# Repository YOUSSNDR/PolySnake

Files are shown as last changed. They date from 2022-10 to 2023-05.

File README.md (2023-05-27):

# PolySnake

<p align="center">
  
</p>

## Introduction

Nowadays, the world suffers from many natural disasters which cause **hundreds** or even **thousands** of victims every year. For example, according to [1] the 1976 Tangshan earthquake was an earthquake that hit the region around Tangshan which ravaged 85% of the buildings in the. The official report claimed **242,769 deaths**, but when considered the missing, the injured who later died, and the deaths in nearby Beijing and Tianjin, making it the deadliest earthquake in China and among the top disasters in China.  

Thus, in order to optimize the search for people who disappeared in this kind of disaster, it is important to design robots capable of sneaking into closed spaces and locate themselves in their environment which is the main goal of our project.  
However, not having yet the capacities nor the time to carry out a robot of this amplitude we will be satisfied to program our project so that it can locate himself by following red arrows for now .

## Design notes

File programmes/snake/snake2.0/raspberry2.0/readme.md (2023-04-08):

## Python program

we will be using the library Serial(from pyserial) 

#### Arduino serial
we will be using two arduino an Uno and a Nano
the serial.Serial allow us to connect the port to the python program

#### def read
here we read de value printed by the arduino nano

#### def write
here we send a value to the arduino Uno

#### def image processing
here we have to read an image in order to find out which path we need to take

### Main program
we use an infinite loop where we:
- read the arduino nano
- if the value is above 8 cm:
    - send nothing to UNO(keep going forward) 
- else if the value is 8 or under:
    - send value to UNO (stop the movment)
    - start the image processing protocol
    - send a new value to the UNO (chose a path)

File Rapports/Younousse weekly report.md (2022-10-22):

# <p align=center> <ins>POLYSNAKE</ins>    
# <p align=center> <ins>REPORTS</ins>

Soufiani

Younousse

<ins>2022/2023</ins>

## <p align=center> Session 1
<ins> 14/10 <ins>

I have started to schematizes some simple situation to visualize how the program will work.
Situation 1(left turn):
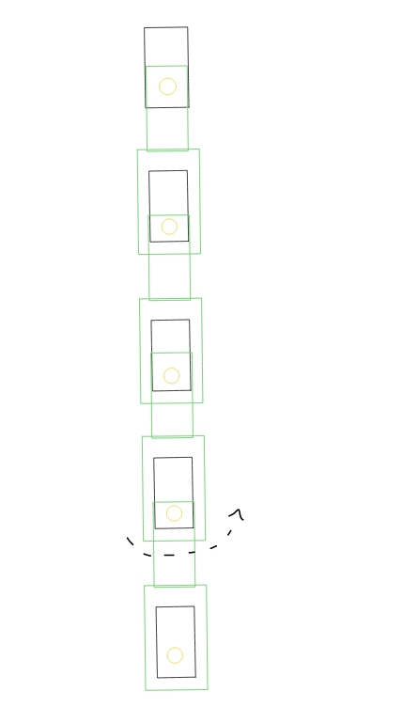
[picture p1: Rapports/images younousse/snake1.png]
how it works
  
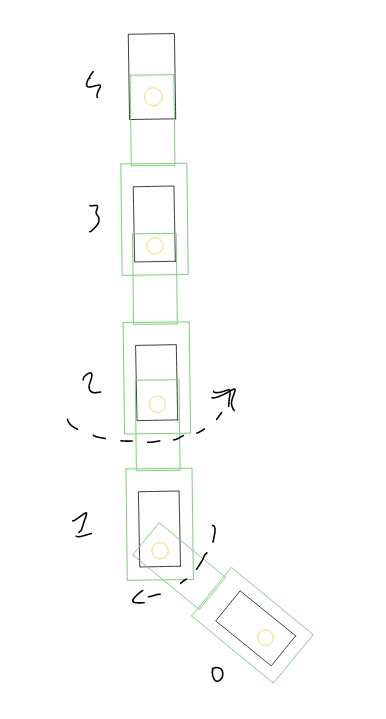
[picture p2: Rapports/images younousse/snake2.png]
how it works2

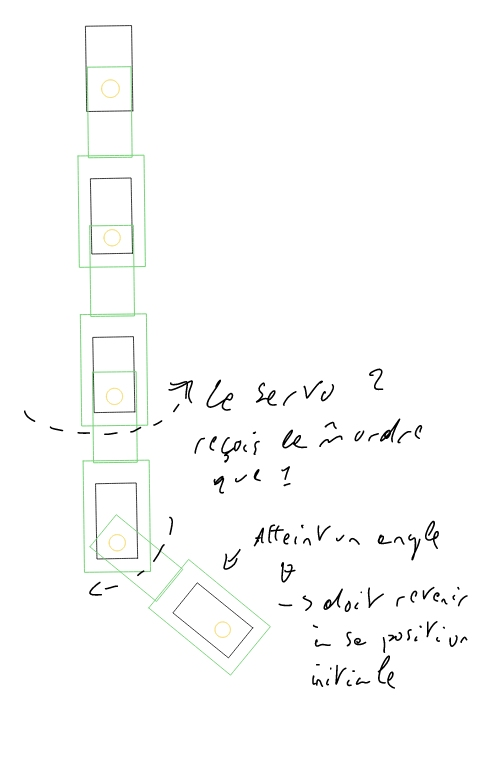
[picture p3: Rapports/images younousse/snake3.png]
how it works3

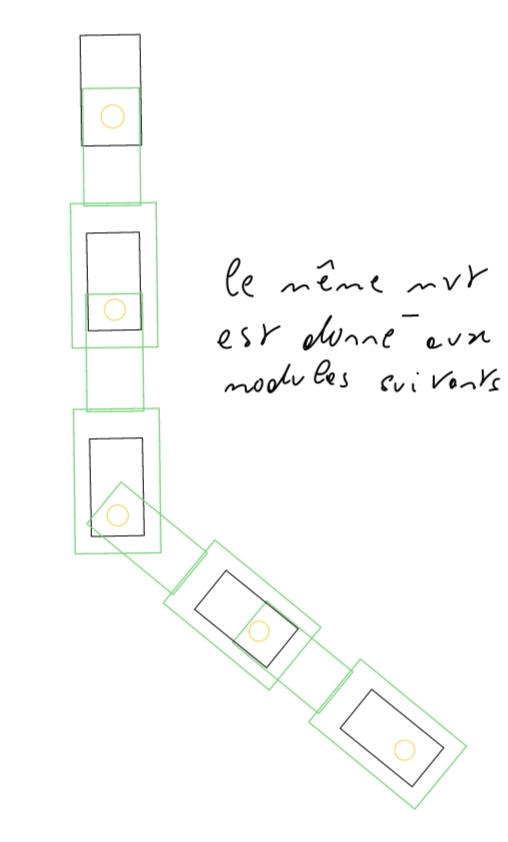
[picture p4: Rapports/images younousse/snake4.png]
how it works4


study of the servomotor and the Arduino library needed to use it.
I start by moving one servomotors then two of them.
There is the program used:
[program test1](https://github.com/YOUSSNDR/PolySnake/blob/main/programmes/servomoteurs/test1/test1.ino)
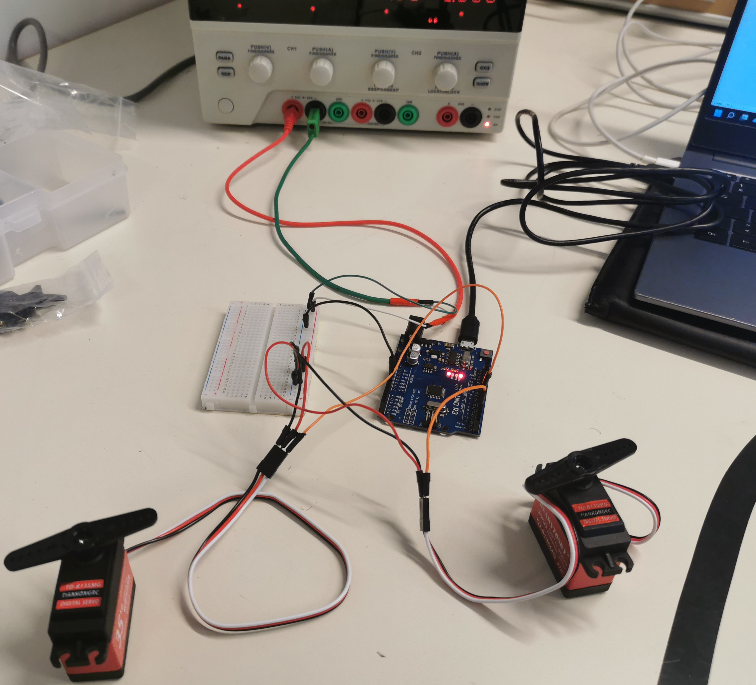
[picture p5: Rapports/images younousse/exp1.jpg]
image du test1


They are troubles with the servomotors:
- some unwanted movement
- trouble to reach the ask angle
- issues to synchronize the servomotors together
Those issues may come from the fact that those servomotors unlike the usual I use goes to 270 degrees. 
I will have to gather more data about them.

## <p align=center> Session 2
<ins>18/10</ins>

[docs about the servomotor](https://fr.aliexpress.com/item/4000538643378.html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)

i tried to find the issues by controlling the servomotors with a potentiometer and with the help of the Teacher, two source of problem were found:
- The système did not had enough courant to run properly, to fix that we will go from 400A to 850A for each servomotors.
- the servomotor had some troubles to rotate some times, we have to create some loop to avoid asking him an angle to big with not enough time.
the [program test1](https://github.com/YOUSSNDR/PolySnake/blob/main/programmes/servomoteurs/test1/test1.ino) have been improve to use the potentiometer

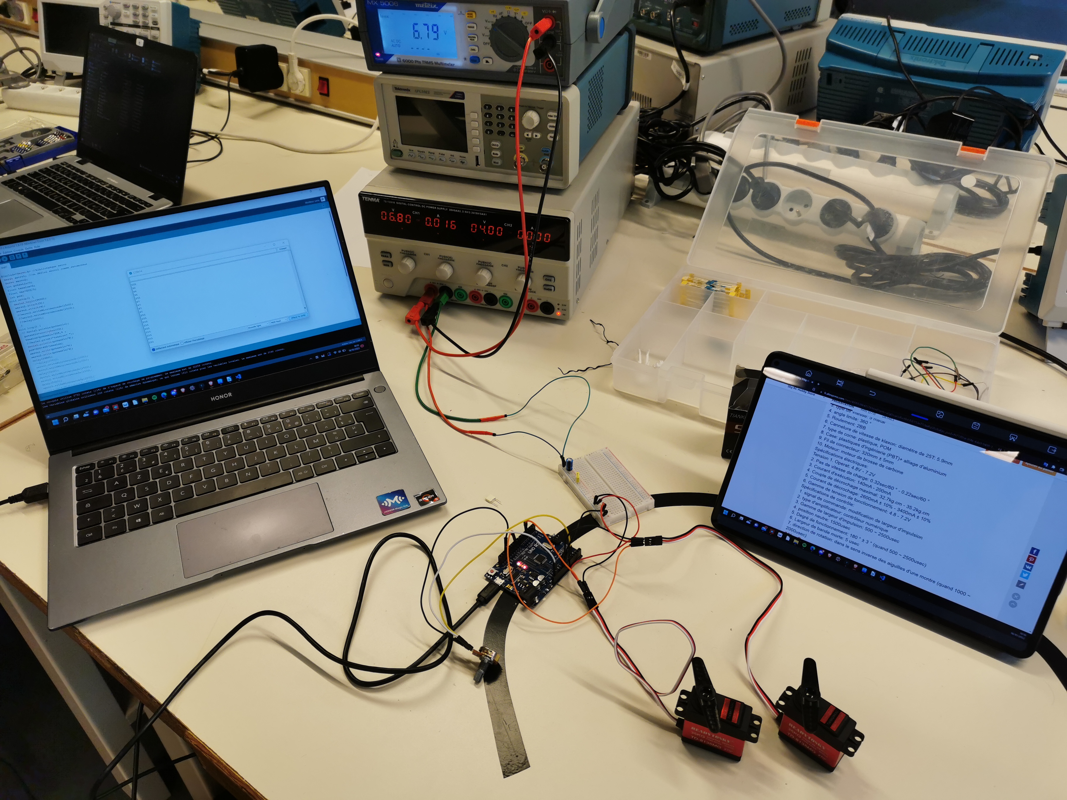
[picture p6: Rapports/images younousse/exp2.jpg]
image du test2


And so we can return to the test witheout potentiometer this time we use an other program. [program test2](https://github.com/YOUSSNDR/PolySnake/blob/main/programmes/servomoteurs/test2/test2.ino)

in it we use directly the microseconds to move the servomotors because the angle are not precise in degrees directly.

The issue look to come from the library use, it might consider 270° which is the max angle of our servomotor for 180° which is the max angle for the sevomotors often use with this library.
  
I will have to check this for the next time.

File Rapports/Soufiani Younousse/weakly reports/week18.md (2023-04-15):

## <p align=center> Session 21
<ins>11/04</ins>

Today, we work on the python program to recognise arrows thanks to a camera.
This program will allow the raspberry to choose the direction by reading an arrow.

For this program we will be using the cv2 library.
As i have never used this library before i will have to learn.
For that i searched to see if someone had ever tried making the same program before, i have found a discussion on stackoverflow on [How to detect different types of arrows in image?](https://stackoverflow.com/questions/66718462/how-to-detect-different-types-of-arrows-in-image)
and from there i have tried two programs.
They both work with the same principle, which is reading the contour to find out if it matches with the one of an arrow.

The first one i have tried was the one of stateMachine (the first one who answerd) however as i still don't master this library i could not make this one work.  
There is the program: [cameraprogram1](https://github.com/YOUSSNDR/PolySnake/blob/695c97967ed71693cd3f5189af5707c93969878c/programmes/Cam%C3%A9ra/image%20recognition%201/testimgrec1.py)  
I might come back on this one later ones i have learned enough to understand the library.

The second program comes from Prefect (another person who answered) this one i was able to make it work.  
Here is the program: [cameraprogram2](https://github.com/YOUSSNDR/PolySnake/blob/695c97967ed71693cd3f5189af5707c93969878c/programmes/Cam%C3%A9ra/image%20recognition%202/testarrowrec2.py)

For the test i use images found on the forum which are:  
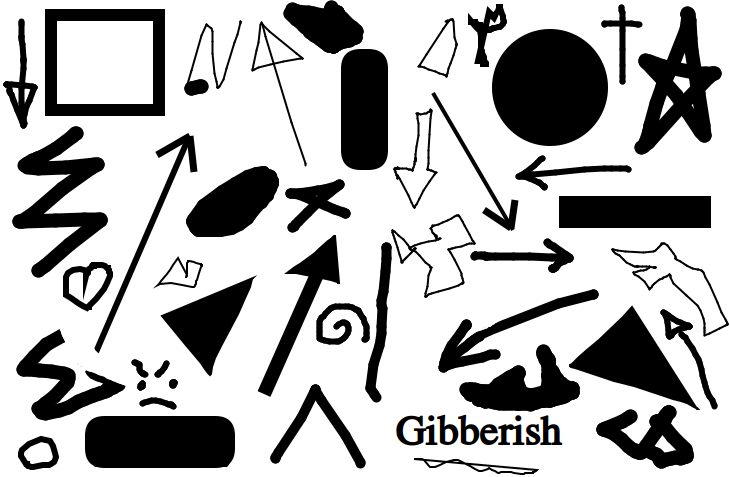
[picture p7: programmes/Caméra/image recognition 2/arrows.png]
This one   
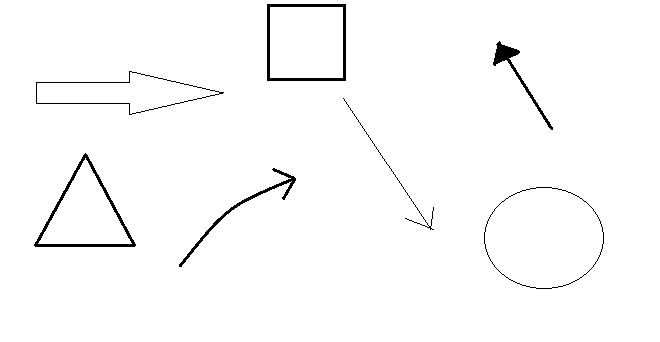
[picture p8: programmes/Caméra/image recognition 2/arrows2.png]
And this one 

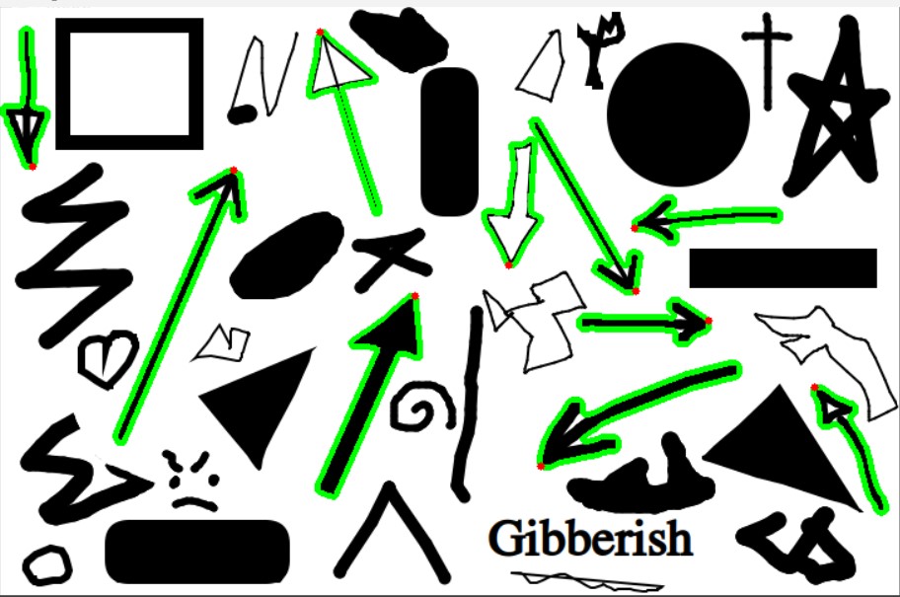
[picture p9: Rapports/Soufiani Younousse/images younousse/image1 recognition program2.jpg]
img1recpg2
The program worked perfectly with the first image   
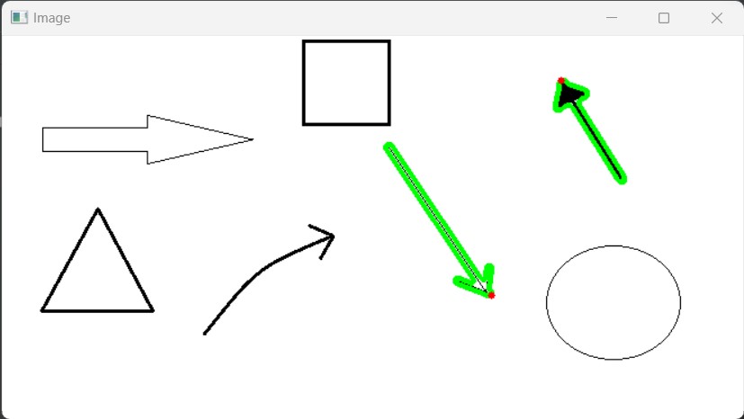
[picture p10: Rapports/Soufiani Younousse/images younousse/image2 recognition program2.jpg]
img2recpg2
But had troubles recognising all the arrows on the second image 

I have also tried getting help from chatGPT which end up with a working programm however less efficient than the other one.
The programm used is this one: [cameraprogramchatgpt]()
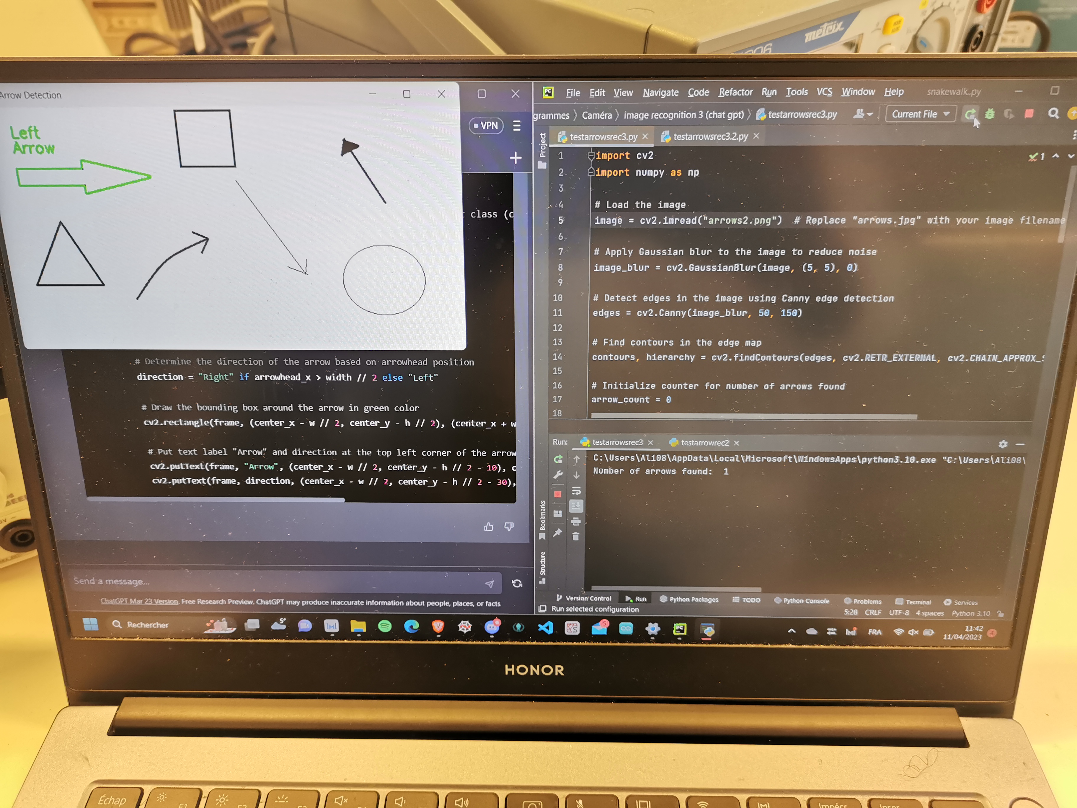
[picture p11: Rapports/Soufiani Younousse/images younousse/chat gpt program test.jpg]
img2recpgchatgpt


I will continue working on the program, Nino (a coworker) gave me a programm to try.
I will see if i can inprove it for the final use.
Guillaume (an other coworker) advise me to try to fill the arrows with easily recognisable colors for the program to detect it easier.
I will see all that.

For this session i have also took an arduino nano, which will carry the ultrasound sensor program.
I had first to weld the pin to it.

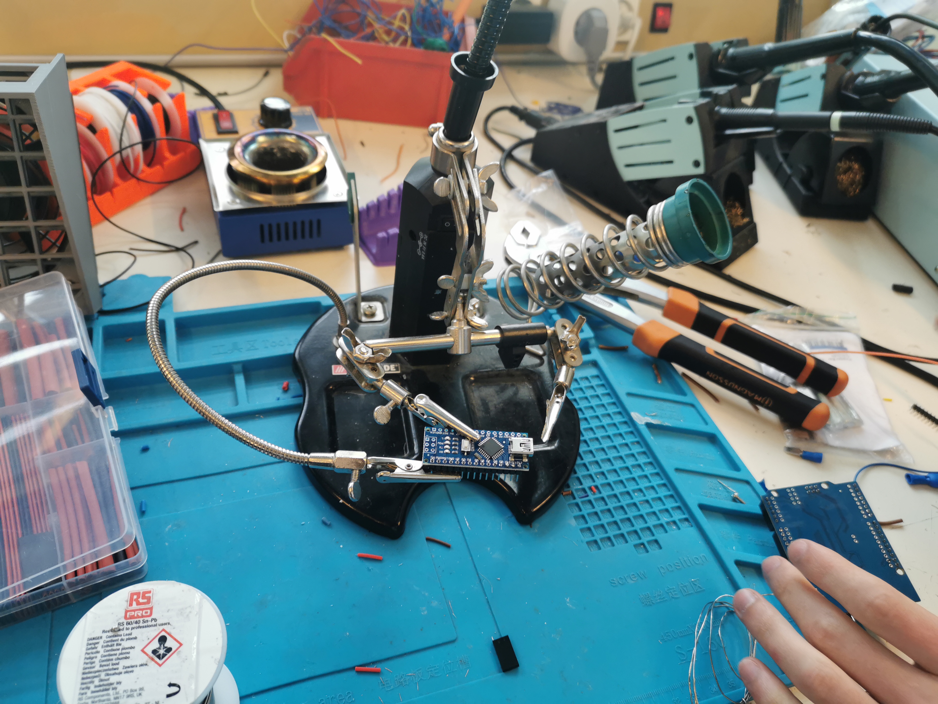
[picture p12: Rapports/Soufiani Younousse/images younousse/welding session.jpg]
welding session
Welding session: 

For the programm testing part i will have to do that at home.

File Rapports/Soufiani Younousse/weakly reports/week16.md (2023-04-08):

## <p align=center> Session 19
<ins>28/03</ins>

My goal this session was to modify the program to make it easier to use with a sensor. 
The issue we had with the program we currently use was that the main function allowing the slithering motion could not be interrupt before the end of a for loop incrementing from 0 to 360.
Which mean that the snake would have to finish his movement before changing direction (for exemple). However we want the snake to stop exactly when the order to stop is given.

Also at the end of the slithering movment the snake will stop if the function is not called again,we will also change that.

Here is the old programm (the test version): [snakewalkV5](https://github.com/YOUSSNDR/PolySnake/tree/main/programmes/servomoteurs/D%C3%A9placement/snakewalkV5.0.0)

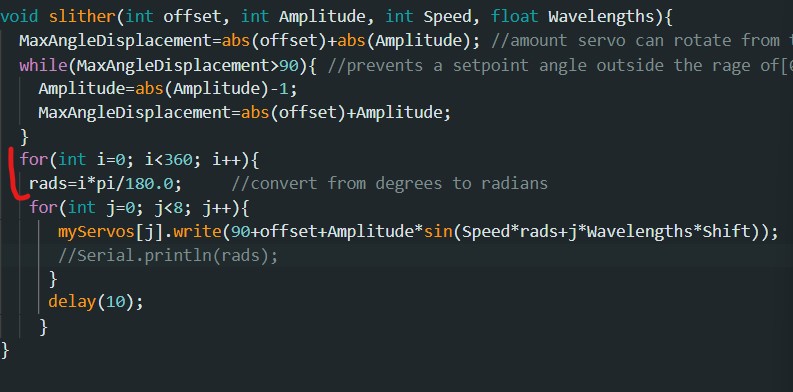
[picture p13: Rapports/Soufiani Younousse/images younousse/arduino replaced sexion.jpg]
replaced sexion
there is what we whant to change: 

I have changed the for loop by a while loop which depend on a boolean variable so that if the variable return false everything stop, else the motion never stop.

Here is the new programm: [snakewalk condition](https://github.com/YOUSSNDR/PolySnake/tree/main/programmes/servomoteurs/D%C3%A9placement/snake_walk_condition)

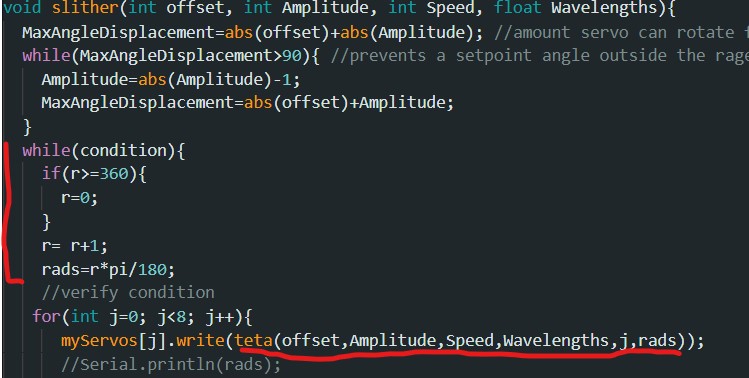
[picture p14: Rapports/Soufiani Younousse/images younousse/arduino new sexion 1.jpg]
new lines
And there are the modified lines: 

after test the new program worked just as good as the old one:
[test new program](https://drive.google.com/file/d/1erZ7xjgxGs1opVZJJl6YyXE4TiV0hOvc/view?usp=sharing)

What we will do now is add a function to modify the values in the slither function to make it turn. And for that i will use the Opencv library which allow me to send datas from python to the arduino. I have made a couple test which did not worked, the python program seems to have trouble to connect with the card, i will have to fix that.

There is the last program (not ready yet):
[New program V2](https://github.com/YOUSSNDR/PolySnake/tree/main/programmes/servomoteurs/D%C3%A9placement/snake_walk_condition2)

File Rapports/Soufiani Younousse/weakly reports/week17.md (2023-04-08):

## <p align=center> Session 20
<ins>04/04</ins>

For this session i have started by trying to find a way to keep the snake head looking at the target by assuming that in any time the sum of the angle made by all the servo motor thanks to the formula use would be constant and equal to zero, how ever i could not demonstrate it at the moment. As it is not the most important part for now i have stopped working on that.

I then switched on a main issue still left, the distance perception. To fix this issue i have choose to add an ultrasound sensor which we would use with an arduino nano. Using the arduino nano may cost more energy but thank to it we avoid Timers issues and also we will be able to read information while the snake will be moving at any time.

Now that i had the idea, i had to find a new way to make communicate the different arduino with the raspberry. I wanted to use the Opencv library but i have finally changed to the pyserial library after asking to Guillaume (a coworker).

Now that i had all the pieces of the final programm, i needed to see how they would all work together.
For that i have created markdown document explaining which program would be use where and what for. here it is -->
[programs explaination](https://github.com/YOUSSNDR/PolySnake/blob/1201f99eacff5840884c5b49c1f553cf679b7878/programmes/snake/snake.md).

All that left us with aproximatly 4 programm to create or upgrade:
- [snakewalk](https://github.com/YOUSSNDR/PolySnake/blob/1201f99eacff5840884c5b49c1f553cf679b7878/programmes/snake/snake1/arduino%20uno/snake_walk_condition/snake_walk_condition.i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) (from arduino) which need to be upgrade and adapt.
- [ultrasound sensor](https://github.com/YOUSSNDR/PolySnake/blob/1201f99eacff5840884c5b49c1f553cf679b7878/programmes/snake/snake1/arduino%20nano/distance/distance.ino) (from arduino) which also need to be upgrade and adapt.
- [communication](https://github.com/YOUSSNDR/PolySnake/blob/1201f99eacff5840884c5b49c1f553cf679b7878/programmes/snake/snake1/raspberry/python1.py) (in python) which need to be upgrade.
- and finally the camera detection part (in python) that we need to create and add in the [communication](https://github.com/YOUSSNDR/PolySnake/blob/1201f99eacff5840884c5b49c1f553cf679b7878/programmes/snake/snake1/raspberry/python1.py) program.

Also to make the communication program clearer there is a [readme](https://github.com/YOUSSNDR/PolySnake/blob/1201f99eacff5840884c5b49c1f553cf679b7878/programmes/snake/snake1/raspberry/readme.md) explaining all the function in it.

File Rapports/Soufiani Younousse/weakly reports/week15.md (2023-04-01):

## <p align=center> Session 18
<ins>21/03</ins>

In this session we have mostly tried to fix an issue on the snake.

So to start the session we wanted to try our program again to see what we could improve next, either on the snake and in the program.
But as i ve started uploading the program in the arduino we have got an error. error

after searching a bit i ve found out that some of my libraries where missing (Servo.h and cvzone.h) so i had to get them back (or at least Servo.h) to run the test.
after the installation there where no more problem with the libraries.
However in the test the snake was not totally working as it was last week.
A servomotor had troubles to turn :
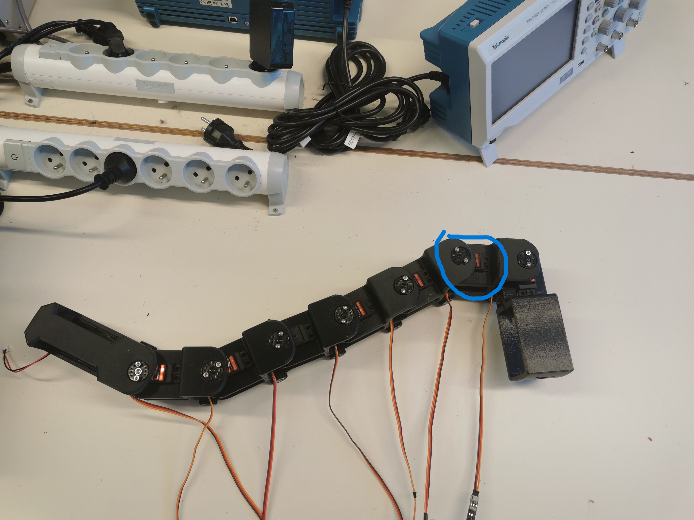
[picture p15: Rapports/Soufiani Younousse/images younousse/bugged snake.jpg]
bugged snake


The probleme looked a bit as the one we had at the start when the servomotor where struggling to reach an asked position.
To fix this issue the solution were to:
- give it enough current to run properly each servomotor.
- if that was not the solution then it meant that the servomotor did not had enough time to reach the asked position.

But here the problem did not came from those two assumption.
Audric (My coworker) Thought that maybe it was the servomotor wich did not work, So we have tried to move the servomotor separetly with a more simple program.
[servo test](https://drive.google.com/file/d/1sBgIdRgADSiTIa0Xv_KnTtk07N9oUKNa/view?usp=share_link)
And the servomotor did work, the last thing left was to verify the program.

Thank to Guillaume we have found this issue:
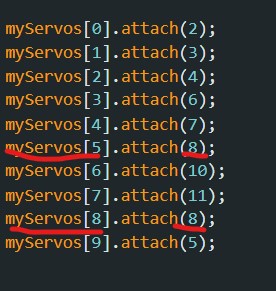
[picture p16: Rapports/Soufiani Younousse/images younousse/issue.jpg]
issue


One pin was receiving two different orders, I probably forgot to change the servo 8 pin last time i have used it and as i did not use it in the main program i thought that it would not affect the rest of the snake.
After fixing that, the snake finally worked as it should have:
[fixed snake](https://drive.google.com/file/d/1Kew2NjVZXMZn-QXQE4DfPmHUft6UFAHi/view?usp=share_link)

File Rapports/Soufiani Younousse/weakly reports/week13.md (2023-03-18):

## <p align=center> Session 16
<ins>07/03</ins>
Work on the rasberri pi zero 1W:
the .conf had trouble to work.
after a restart i have found an error in the text of the ".conf" file, after fixing it the raspberrypi finally appeard with the others devices connected to my wifi point.
normally to use the ssh conection you need to use the command "ssh pi@raspberry" if it is on factory settings.
you will next have to enter the password witch is normally "raspberry".
after that done you will be in the terminal of the raspberry card which work like a linux terminal, you can now update an install the needed package (command: "apt update","apt upgrade").
we will need python so i have installed pyhton3 (apt install python3).
We will next have to learn openCV and install it in the raspberry.

I have update the tutorial on how to connect the raspberrypi:
[tutorial](https://github.com/YOUSSNDR/PolySnake/blob/2c97e4ca37ce17a8575b1211ac05783869601126/Raspberry%20pi/Raspberry%20pi%20zero%20config/config%20Raspberry%20pi%20zero%20W.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)

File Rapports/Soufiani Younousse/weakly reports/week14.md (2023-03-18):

## <p align=center> Session 17
<ins>13/03</ins>

For this Session we made a lot of tests and verify a theorie we had.

### Cleaning Time:
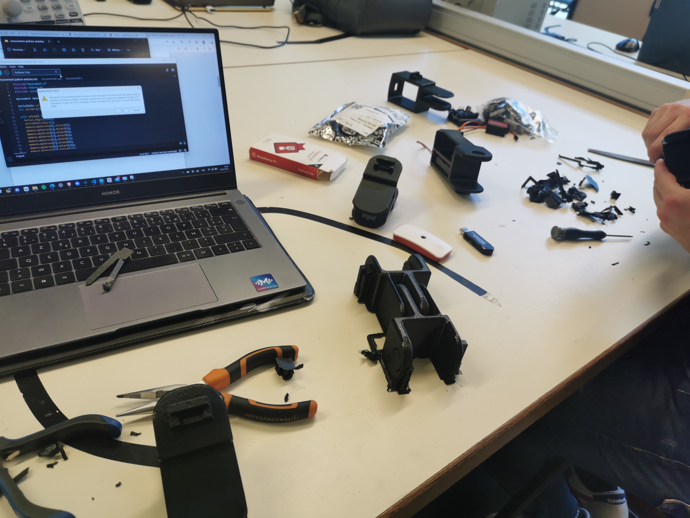
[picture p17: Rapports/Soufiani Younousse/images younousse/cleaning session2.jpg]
cleaning session2.1
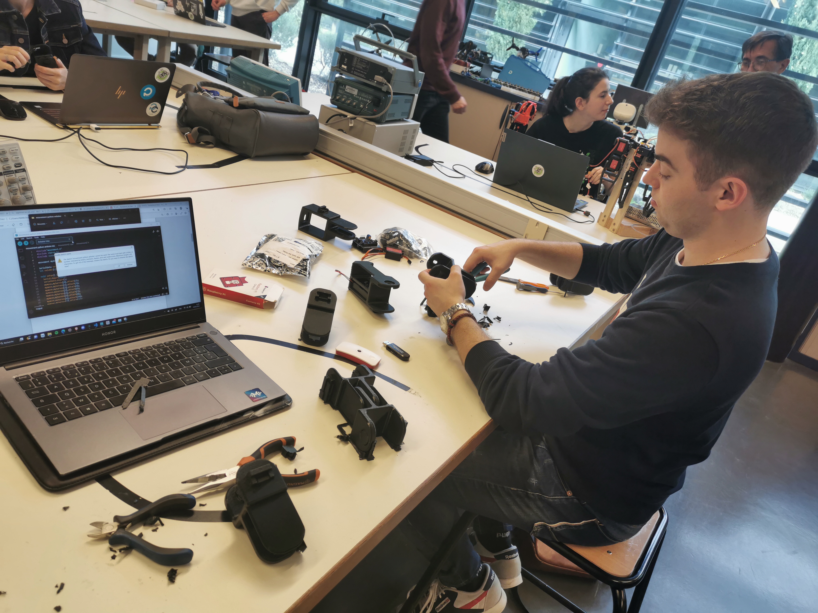
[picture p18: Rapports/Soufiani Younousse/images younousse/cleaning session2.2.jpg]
cleaning session2.2
So first we start the session by cleaning the new pieces   

Those new pieces can be mounted on wheels which will allows us to make the first tests on wheels.

### tests session:
The idea we had was that more of the work on the slithering motion was made by the friction.
And as it was pretty complicated to make a snake skin we have chosed Rubber wheels (as they will roll if the force that they receive is parallel to them and will be blocked more and more by friction as the force get perpendicular to them).
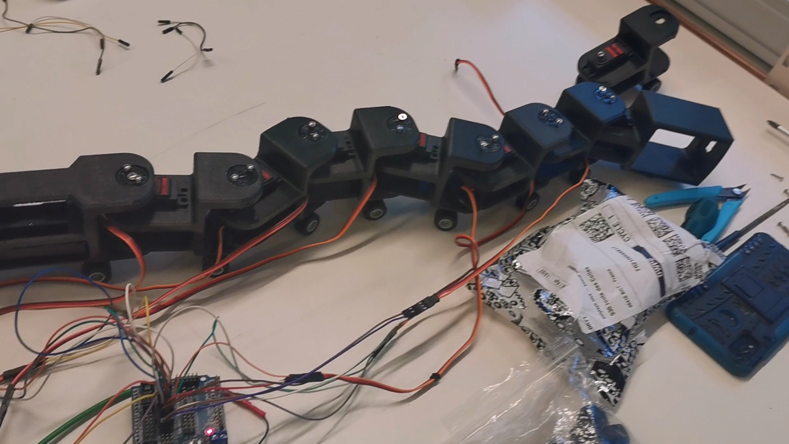
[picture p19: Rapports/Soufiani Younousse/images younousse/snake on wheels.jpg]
snake on wheels
after assembling the snake and initialising the servomotors it looked like that: 

then we used those [different program](https://github.com/YOUSSNDR/PolySnake/tree/main/programmes/Classes/mouvement) to make it move:

- the first test worked but with some troubles, as the snake make movement that are too big we have to much friction.
However we can modify parameters on the snake movement in the program. 
- After multiple test we have understood that we needed to find an equilibrium between Amplitude and Wavelength (at some point to increase the the amplitude but avoid to much friction we needed to increase wavelengths which actually decrease the amplitude).
- we saved the characteristics which where working good togethers an offset of 3(to regulate a default either on the conception or in the initialisation which was making the snake going lightly to the right) an amplitude of 43, a speed and a wavelength of 2 (those measures have not equivalent with reality for now as the different characteristics change as we modify the pieces so we need to take mesurements to find the coeficient given in reality). 

the line of code looked like this in the code: 

slither(3,43,2,2)

here are some footage of the snake slithering thanks to the wheels:
[snake on wheels2 ](https://drive.google.com/file/d/16HxC7rm6nMEpBZPa2jUxAVyJ_MZUEDOj/view?usp=share_link), [snake on wheels3](https://drive.google.com/file/d/110NtvDqg1qCNGc-kb5Mu2t1d70bv_1B8/view?usp=share_link)

### Research:
To verify my thoughts i have looked for articles one of them made some good points ([the article](https://www.pnas.org/doi/10.1073/pnas.0812533106)).
I have noted a couple sentences which where going with my thought:
- unlike most other terrestrial organisms of this size, body inertia is not central to slithering locomotion. Motion instead arises by the interaction of surface friction and internal body forces.
- these scales provide the snake a preferred direction of sliding on surfaces of sufficient roughness and compliance
- Another aspect that we have not considered is that snakes are likely able to dynamically change their frictional interactions with a surface by adjusting the attitude of their scales

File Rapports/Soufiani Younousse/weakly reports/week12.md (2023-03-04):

## <p align=center> Session 15
<ins>28/02</ins>
Work on the program: i have tryed a new way to cut the slither program with a "switch-case", but i could not test this [new program](https://github.com/YOUSSNDR/PolySnake/blob/b902d92297fb181699cc290238d12c17dca581ae/programmes/test/test%20mouvement/snakewalk-case4.ino/snakewalk-case4.ino.ino) yet.
here we only kept four cases as said in the last session:
- line (snake in line)
- slither (the snake go forward)
- slither right (the snake take a right turn)
- slither left (the snake take a left turn)
- stop (the snake stop his mouvement)

Also we will have to modify another point on the slither program so that we can get an endless loop which the "switch-case" will modify.

Verification of the component, as the Raspberry pi zero 2W is on limited stock it was much harder to found, We finally selected [this product](https://fr.aliexpress.com/item/1005003496928208.html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).

I have also worked on another way to work with the raspberry pi (if equiped with wifi) by using ssh.
It is not finished yet but i am also writing down all the details on how to connect the raspberry pi so that the tutorial could be used for the next Raspberry pi and also by someone else.
Here is the [tutorial](https://github.com/YOUSSNDR/PolySnake/blob/b902d92297fb181699cc290238d12c17dca581ae/Raspberry%20pi/Raspberry%20pi%20zero%20config/config%20Raspberry%20pi%20zero%20W.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) (not finished yet).

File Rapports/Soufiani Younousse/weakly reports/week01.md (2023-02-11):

# <p align=center> <ins>POLYSNAKE</ins>    
# <p align=center> <ins>REPORTS</ins>

Soufiani

Younousse

<ins>2022/2023</ins>

## <p align=center> Session 1
<ins> 14/10 <ins>

I have started to schematizes some simple situation to visualize how the program will work.
Situation 1(left turn):
how it works  
how it works2
how it works3
how it works4

study of the servomotor and the Arduino library needed to use it.
I start by moving one servomotors then two of them.
There is the program used:
[program test1](https://github.com/YOUSSNDR/PolySnake/blob/main/programmes/servomoteurs/test1/test1.ino)
image du test1

They are troubles with the servomotors:
- some unwanted movement
- trouble to reach the ask angle
- issues to synchronize the servomotors together
Those issues may come from the fact that those servomotors unlike the usual I use goes to 270 degrees. 
I will have to gather more data about them.

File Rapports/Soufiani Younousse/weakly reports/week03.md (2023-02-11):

## <p align=center> Session 3
<ins>28/10</ins>

### <ins>Homework</ins>

I had to verify the angle at home in order to do that i had plan to :
- first ask the servomotors for an 90° angle to see if it shows the center
- then ask him an angle of 180° to see how the library work 

However being at home i did not had acces to an efficient generator so the servomotor was strugling to get to the asked angle.

My solution was to create a loop asking him to move angle by angle while letting him enough time to reach each one of those.
to fond the needed time i have used the [docs about the servomotor](https://fr.aliexpress.com/item/4000538643378.html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) which give the rotational speed in both direction and chosed there the biggest time.
which left me with 0.32s/60° convert that giving me a little less than <span style="color:red">0.006s/1°</span>.

That left me with this code:
 [program test angles](https://github.com/YOUSSNDR/PolySnake/blob/main/programmes/servomoteurs/test_angles/test_angles2/test_angles2.ino)
 the program worked but still strugle at the initialisation.

### <ins>ClassWork</ins>

I have started by some simple test to move one servo motor but it was strugling to move even with a generator.
The reason was a missunderstood of myself the generator only limitate to some intensity and the servomotor take the intensity it need so  i had to go to 1.2A on the generator even knowing that the [docs about the servomotor](https://fr.aliexpress.com/item/4000538643378.html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) ask for 0.2A.

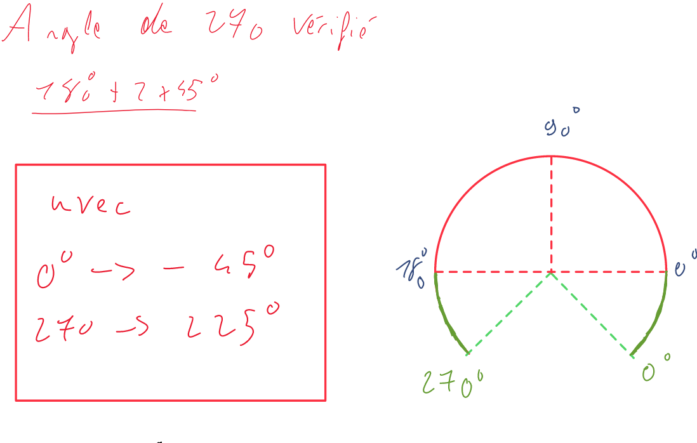
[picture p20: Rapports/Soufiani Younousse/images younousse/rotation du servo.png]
Rotation du servo
then using an upgrade of the program test2 [program test2_2](https://github.com/YOUSSNDR/PolySnake/blob/main/programmes/servomoteurs/test2/test2_2.ino) i have verified the minimum and maximum angles. an obtained this 

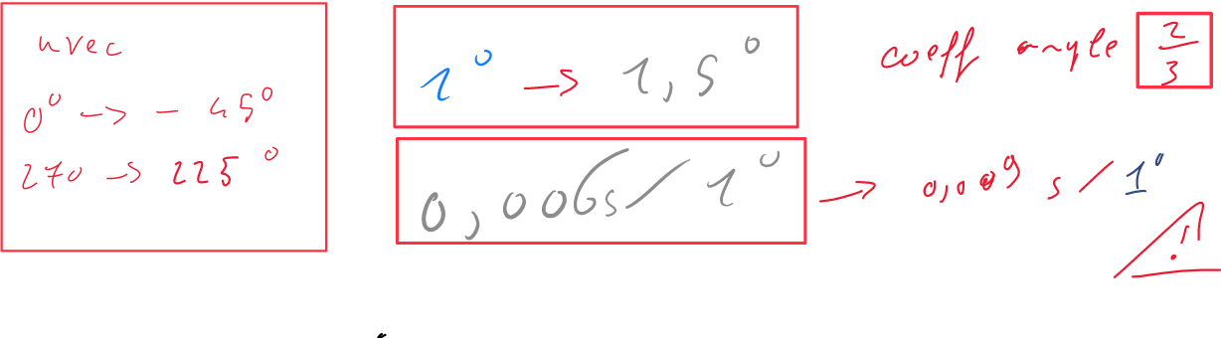
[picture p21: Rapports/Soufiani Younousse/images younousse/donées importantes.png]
donées importantes
which give us a <span style="clor:red">coefficient of 2/3</span> betwin the asked angle and the obtain angle which give us those important datas 

i have also been able to try two servomotors moving at the same time with the create program [snake walk](https://github.com/YOUSSNDR/PolySnake/blob/d8df9ac458cd2a9e06b5fb9730dac2725eff6cc4/programmes/servomoteurs/D%C3%A9placement/snake%20walk/snake%20walk.ino),
which is only a test for now which will be upgrade next to mimic the snake ondulation.

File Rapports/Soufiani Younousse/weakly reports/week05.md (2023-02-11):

## <p align=center> Session 5
<ins>26/11</ins>

We have received some servomotors with 180 degrees angle which is enough for our snake and limit the risks of braking the snake by going to far on a test.

Then there was a test  of the program [snake_walkV2](https://github.com/YOUSSNDR/PolySnake/blob/d8df9ac458cd2a9e06b5fb9730dac2725eff6cc4/programmes/servomoteurs/D%C3%A9placement/snake%20walk%20V2/snake%20walk%20V2.ino) after correcting all the little mistakes made before. 
multiple issues appeared:
    - first the program which normally work in four steps had only two of them working, this was because of the conditions. Step 1 worked because of the initialisation and then step 3 always had the conditions to work.
    - The servomotors decided not to work "again", but this time not because of lack of intensity and voltage drop. I have changed the wires but still nothing moved even with some simple test programs [test3](https://github.com/YOUSSNDR/PolySnake/blob/main/programmes/servomoteurs/test3/test3.ino) and [test4](https://github.com/YOUSSNDR/PolySnake/blob/main/programmes/servomoteurs/test4/test4.ino). with the help of a teacher it finally worked, i am still not sure of why it did not worked before. the servomotors starts working rigth after the mulitmeter have been plug, for the teacher it is a fake contacte somwere (but i have changed the wires before) after that they where some litle bug but they where working. i will reduce next time the number of wires to limit the risks of fake contact (i will need some longer wires).

After that i have tried again the [snake_walkV2](https://github.com/YOUSSNDR/PolySnake/blob/d8df9ac458cd2a9e06b5fb9730dac2725eff6cc4/programmes/servomoteurs/D%C3%A9placement/snake%20walk%20V2/snake%20walk%20V2.ino). but still nothing moved they where some other mistakes in it :
        - the program was still making simultaneously the two same steps because the end condition of the two steps where matching each others.
        - even if the steps where passed still not any movement where made.

I decided after that to make a new program as this one already had multiple default at his creation as seen on week4 (already difficult with three servomotors it would be even worse with eight ) and another program would be needed to control more servomotors. It will be finished for or during next session and will be named [snake_WalkV3](https://github.com/YOUSSNDR/PolySnake/blob/main/programmes/servomoteurs/D%C3%A9placement/snake%20walkV3/snake%20walkV3.ino).

A sheet explaining how i want to make it work is available here on [snake_walkV3_sheet](https://github.com/YOUSSNDR/PolySnake/blob/main/Rapports/Soufiani%20Younousse/images%20younousse/test%20angles%20servos.pdf).
The program will use a list containing all the angle in the order they need to be ran and each servomotors will follow the list whith a shift depending on their position.

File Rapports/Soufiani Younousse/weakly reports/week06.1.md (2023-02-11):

## <p align=center> Session 6
<ins>06/12</ins>

I have worked home on the new programm [snake_WalkV3](https://github.com/YOUSSNDR/PolySnake/blob/main/programmes/servomoteurs/D%C3%A9placement/snake%20walkV3/snake%20walkV3.ino) as planed in the last session.

the goal in this new program was to make a list of angle which would have been followed by every servomotors with a shift between them in order to mimic the snake ondulation.
the issue was that i had not found a proper way to put all the servomotors in a loop.
Therefore I needed conditions in order for the loop to work as intended.
Also we needed to control the speed of those servomotors.

I tried to make a class ([move.h](https://github.com/YOUSSNDR/PolySnake/blob/main/programmes/servomoteurs/D%C3%A9placement/snake%20walkV3/move.h) [move.cpp](https://github.com/YOUSSNDR/PolySnake/blob/main/programmes/servomoteurs/D%C3%A9placement/snake%20walkV3/move.cpp))to resolve the issues of how to follow the list but the conditions case i have putted where not recognised by the c++ language.

To help me with the program my coworker lead me to a link of someone which had already worked on a snake robot before.
[programofWillDonaldson](https://github.com/WillDonaldson/Robotic-Snake/blob/master/_1D_robotic_snake/_1D_robotic_snake.ino).
in his program i have learned some important comand as "Servo myservo[10];" which he use to define 10 servomotors.
this command can simplify a lot of work as in a loop we can change servo by using a variable.

Also the movement that i wanted to replicate is on his programe with the fonction named slitther.
I have noticed the use of a mathematical formula "myServos[j].write(90+offset+Amplitude*sin(Speed*rads+j*Wavelengths*Shift));"
which does looks alike the one of an progressive plane wave.

actually the program fit with what we wanted so we have tested it with some pieces of the snake that we already had. 
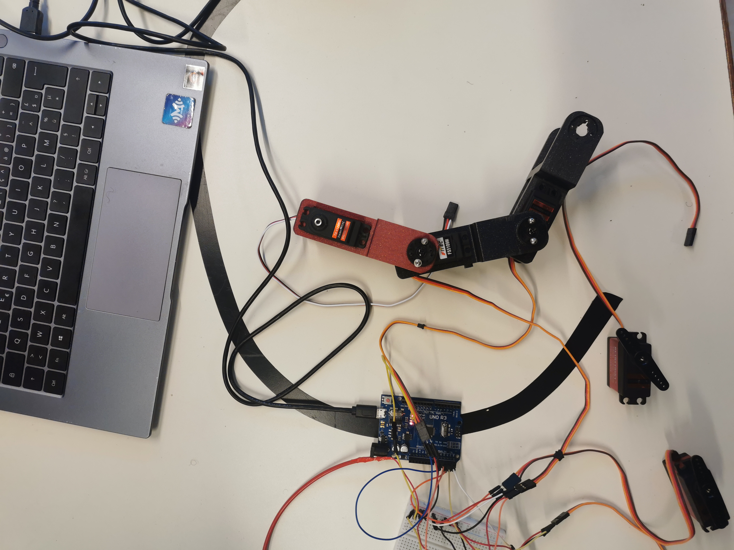
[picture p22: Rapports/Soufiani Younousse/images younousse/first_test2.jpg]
test 1

 which gave us this first result:[first_test](https://youtu.be/3seGkPpCPjw).
here the movement do not look normal because the snake was not initialise before we started the program.
So we know for the next time that while whe assemble the snake all the servomotors must be initialise with an 90° angle.

for the next session i will have to study deeper the program to make a test on a bigger snake.

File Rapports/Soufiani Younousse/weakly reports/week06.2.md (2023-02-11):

## <p align=center> Session 7
<ins>09/12</ins>

We began the session by cleaning the new 3D pieces we had as we needed them for the test.
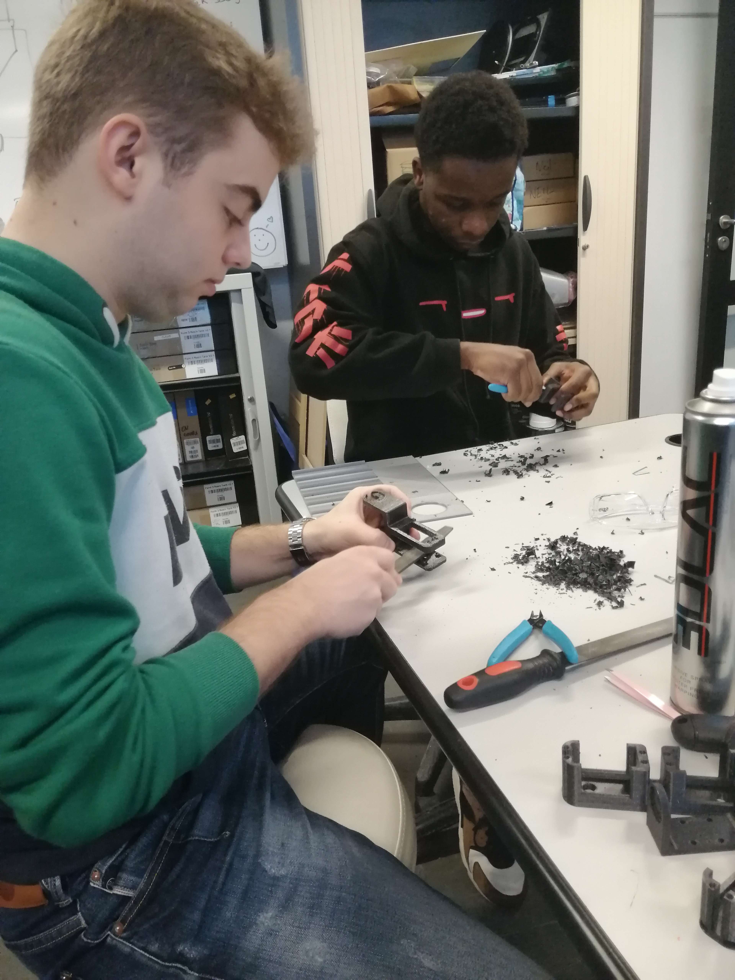
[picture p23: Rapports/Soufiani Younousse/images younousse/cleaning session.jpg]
cleaning time
 

After cleaning all the pieces we could now test the snake.
- First i prepared the programs needed while my coworker was adding the servomotors into the pieces.
- then i pluged all the servomotors so we could initialise all se servomotors at an 90° angle before attaching them (to have all the sermotors forming a straight line in the initialisation).
with [line](https://github.com/YOUSSNDR/PolySnake/blob/main/programmes/servomoteurs/D%C3%A9placement/ligne/ligne.ino)
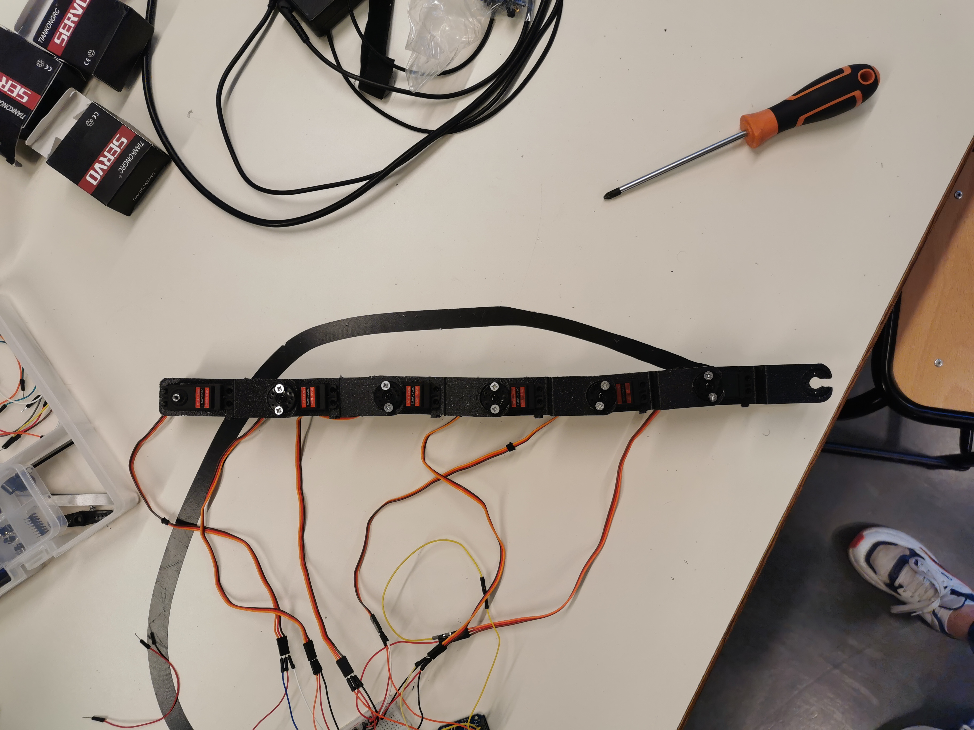
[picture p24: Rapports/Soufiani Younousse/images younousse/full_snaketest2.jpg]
snake

- And so we could start the testing with [servos_testing](https://github.com/YOUSSNDR/PolySnake/blob/main/programmes/servomoteurs/D%C3%A9placement/servos_testing/servos_testing.ino).
which are some simple order. And there is the result [Test servos](https://youtu.be/MFZg65ag1Ys).

Next test was the "snake_walk" (snake ondulation).
for it we used this program [snake walkV5](https://github.com/YOUSSNDR/PolySnake/blob/main/programmes/servomoteurs/D%C3%A9placement/snakewalkV5.0.0/snakewalkV5.0.0.ino).
And here is the result [Second test](https://youtu.be/CUl1Hz0VQxA)

the program use different variable allowing us to modify the mouvement in deffrent way:
- modify the offset allows the snake to in his moves tend to go in a direction (>0 right, <0 left).
- modify the amplitude will modify the height of the sinusoïd top.
- modify speed will increase or decrease the speed of the propagating waves.
- and modify wavelenght will make the waves more or less large.
as it use a formula which looks alike with  the one defining a progressive wave propagating on a 2D plan.

We will verify this next time.
But the main goal for the next session will be to learn how to controle an arduino device with an app.
And for another time we will try to adapt some of the program on a class.

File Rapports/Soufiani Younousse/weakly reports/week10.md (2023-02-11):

## <p align=center> Session 13
<ins>07/02</ins>

We have talked about the components we should use in order for the snake to move.
For that we have study a [video](https://www.instructables.com/Snake-Robot-1/) of a snake looking a bit like our but with multiple wheels,
what is interesting here is that apparently not anny of the wheels are motorised insted the person use the sinusoïdal mouvement which allow the snake thanks to the wheels to go forward.
We are planing on testing that as soon as we receive the wheels.

Also for all the image recognition part i will have to use a Raspberry pi Zero 1 W card which will work like a little compteur and will allow us to make an autonomous robot. In order to use the card we will need multiple component that we will have to order. After research we end up with [this list of component that we need to order](https://github.com/YOUSSNDR/PolySnake/blob/b258c2d82ef8cb8ddd8b45ca130dc0260bcdb722/Achats/Achats.md).
Among them i have put a Raspberry pi zero 2 W witch should be an improved version of the zero 1 W.
Also i have continue my work on the [Computer Vision With Arduino | 2 Hour Course | OpenCV Python](https://youtu.be/mfiRJ1qgToc).
We can now:
- command the program to stop or continue the slither motion witheout reuploading it every time
- connect the arduino board to python 
- make a communication betwin python and arduino

We have now this [arduino program](https://github.com/YOUSSNDR/PolySnake/blob/b258c2d82ef8cb8ddd8b45ca130dc0260bcdb722/programmes/servomoteurs/D%C3%A9placement/snakewalkpython-arduino/snakewalkpython-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) which can work with this [python program](https://github.com/YOUSSNDR/PolySnake/blob/b258c2d82ef8cb8ddd8b45ca130dc0260bcdb722/programmes/Arduinocv/Output/snakewalk..py).

here the value sent with arduino.sendData() in python put the snake in straightline if the value is 1 or continue the motion if the value is 0.

Now we will have to study the image recognition part and reproduce everything in the Raspberry pi.

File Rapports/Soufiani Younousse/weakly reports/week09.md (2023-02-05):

## <p align=center> Session 12
<ins>31/01</ins>

Research of a new motor for the whells, In order to get more torque we might use a continuous rotation servo motor, i have found a tutorial for how to make a continuous rotation servo motor out of a basic servo motor which could be a solution for our motor
[How_to_make_a_360_degree_Continuous_Rotation_Servo_Motor](https://youtu.be/mRO0wfSQ6jw)

We learn here that they are two major step:
- first for the mechanical part, we must flatten the last gear in order to remove the mechanical block and dril it to disconect it from the potentiometer
- then for the electronic part we must disconect the pin of the potentiometer linked to the board and on the board link the signal pin with the positive and negative pin with a resistor(same resistor for each pin)

but we should see first if they are not already made contnuous rotation servo motor.

Change of plans we will be using a material to make the modules behind the head slide on the floor while the head will guide them.
We will have to make some test to found the best motor.

Learning how to use OpenCV python for object recognition. For that i use this video [Computer Vision With Arduino | 2 Hour Course | OpenCV Python](https://youtu.be/mfiRJ1qgToc).
Which help to learn a lot of arduino basics but also some basics with OpenCV
thanks to an arduino library given in the video i will be able to make comunicate python and arduino which will allow me to modificate the mouvement witeout having to download again in the arduino uno.
I will modificate the code for this purpos and continue the video to learn about the image recognition part.

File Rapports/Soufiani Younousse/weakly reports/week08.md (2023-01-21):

## <p align=center> Session 10 and 11

### Holidays Work
for the holidays i have ask for some pieces to run some test by my own.
those pieces were:
- an arduino Sensor Shield V5.0
-  a MDD3A Motor Driver
-  a 2 axes DC 5V motor
wheels_and_MDD3A

card_and_Shield

to run all that i had a 5V power supply.
thanks to the Shiel the connections were modify giving a much clean result. I had trouble using the power supply but i have been able to try a program allowing me to use a joystick to control a servomotor.
[joystic_control](https://github.com/YOUSSNDR/PolySnake/blob/df2c1382a202e414176d68fe3e251ddcb0f33a08/programmes/servomoteurs/test%20controle%20par%20analogue/test%20controle%20par%20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)

### Algorithm course
On those course i worked on a program to detect obstacles.
My first idee was to use an ultrasound sensor to detect obstacles for therefore i took an old program i had and ad a function to move the head of the snake.

there is a photo of the ultrasound sensor working alone:
Ultrasound_sensor
there is the program and a video of the snake analysing his surounding after the slither move:
[surrounding_detection](https://drive.google.com/file/d/1-J1L_gpx6d5yrn2LekHKFwAyNEZ4aanV/view?usp=share_link)

### course session 10
<ins>13/01</ins>
We finally chose an other way for the snake to know when to make a turn, the idea is to use a rasbery pie camera to analyse the image of an arrow giving the direction the snake have to take.

So for this session i chose to work on the program to make the snake go forward or backward for that we use a DC 2 axes 5V motor, i came up with this program:
[Wheels_testprogram1](https://github.com/YOUSSNDR/PolySnake/blob/df2c1382a202e414176d68fe3e251ddcb0f33a08/programmes/Roues/premier%20test/premier%20test.ino)
there is what it looks like:
[heels_test1](https://drive.google.com/file/d/1kCXxd9m7_tPdRNpz16n7oTgrz3TyLUi4/view?usp=share_link)

but it seems that i can only make them turn at fool speed, so i tried another program to try control it:
[Wheels-testprogram2](https://github.com/YOUSSNDR/PolySnake/blob/df2c1382a202e414176d68fe3e251ddcb0f33a08/programmes/Roues/2nd%20test/2nd%20test.ino)

the program allow me to control the speed by raising the tension. We can see that the wheels start to turn at the analogic value of 50 which is around 1V. Nino advised me to use a PWM i will look for it for the next session.

As i was working on the motors my coworker which is working on the "skeleton" of the snake asked me about the max angle took by the snake in the slither move to avoid breaking the new pieces. I had to modify the program to giveme the answer:
[slither_test1](https://github.com/YOUSSNDR/PolySnake/blob/df2c1382a202e414176d68fe3e251ddcb0f33a08/programmes/test/test%20angle%20maxi/test%20angle%20maxi.ino)
So now we know that the max values taken is 120° and as our servomotors are settled on 90° we know that the max angle is 30°.

### course session 11 
<ins>16/01</ins>

#### Presentation
for the first hour and half we have prepared our presentation: I will have to show some of the works done on the snake which in my part are the program to mimic the ondulation: [snakewalk](https://github.com/YOUSSNDR/PolySnake/blob/6e268a2a5f81da5a7a2917bf6dcddee0256f1d06/programmes/servomoteurs/D%C3%A9placement/snakewalkV5.0.0/snakewalkV5.0.0.ino)
and the program to use the motors [wheels](https://github.com/YOUSSNDR/PolySnake/blob/6e268a2a5f81da5a7a2917bf6dcddee0256f1d06/programmes/Roues/premier%20test/premier%20test.ino).

the programes i have took for the presentation are first the [snakewalk_line](https://github.com/YOUSSNDR/PolySnake/blob/6e268a2a5f81da5a7a2917bf6dcddee0256f1d06/programmes/servomoteurs/D%C3%A9placement/transition%20sw-line/transition%20sw-lin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) which allows me to swhow how much can we modify the snake movement as it shows speed variation and the snake taking turn and also the [motor_first_test](https://github.com/YOUSSNDR/PolySnake/blob/df2c1382a202e414176d68fe3e251ddcb0f33a08/programmes/Roues/premier%20test/premier%20test.ino) which only shows the motors going forward full speed and backward full speed.

#### work time

After the presentation we have talked a little about the motors we would use later, we still have not chose one yet so for now i will still continue to work on the 2 axes DC 5V motor.
For my work then i have started to make the programs more clear using by classes it would make them easier to use later.
there are the program:
[movment](https://github.com/YOUSSNDR/PolySnake/tree/main/programmes/Classes/mouvement)
[motor](https://github.com/YOUSSNDR/PolySnake/tree/main/programmes/Classes/moteurs).

I will start making research for the camera and image recognition part.

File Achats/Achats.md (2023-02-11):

## Récap des Achats
#### <ins>03/02</ins>
| Objets  |
| ------ |
|[câble mini HDMI vers HDMI](https://www.amazon.fr/Rankie-C%C3%A2ble-Mini-Haute-Vitesse/dp/B01KRKO4MM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)|
|[Hub USB C(branchement C sortie USB)](https://www.amazon.fr/hub-usb-c/s?k=hub+usb+c)| 
|[adaptateur USB C(entrée) vers USB mini B(sortie)](https://www.amazon.fr/iJiZuo-Pi%C3%A8ces-Adaptateur-Connecteur-Femelle/dp/B0B7RMFMN4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)|
|[Roues Lego](https://www.amazon.com/Lego-Tire-Wheel-Long-Axles/dp/B00XZIMDFO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)|

Comme vu par mail on peut aussi remplacer le hub USB C par un hub USB mini (qui est cependant moins fréquemment utilisé).
Aussi nous pourrions aussi essayer la Raspberry pi zero 2 W qui est plus performante que la zero 1 W : [comparatif](https://raspberrytips.fr/raspberry-pi-zero-vs-zero-2/)

|[hub USB mini(branchement mini USB sorties USB)]( https://www.amazon.fr/Adaptateur-Puissance-Chargement-Raspberry-T%C3%A9l%C3%A9phone/dp/B078M3Z84Z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)|
|-----|
|[Raspberry pi zero 2 W](https://www.ldlc.com/fiche/PB00516087.html#585a4fefd91c5)|

celle-ci a besoins des mêmes éléments pour fonctionner que la zero 1 W.

Avec tout ça la Raspberry nécessitera l'utilisation de souris,clavier et écran  que nous avons normalement déjà à disposition.

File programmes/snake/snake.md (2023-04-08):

### Need to study the wheels
[how snake skin work](https://www.pnas.org/doi/10.1073/pnas.0812533106)

### Snake deplacement (what we want)
- read a distance:(we might use an arduino nano for that)
    - if to short:
        - stop the slither motion
        - look at the obstacle
        - activate the camera
        - take the order
    - else:
    - keep the slither motion 

#### For that we will use :
- an arduino nano card
- an arduino uno card 
- a raspberry zero W card

#### How will they work

- The arduino nano will take the distances continuously and advert the raspberry zero W when the limit distance is reached.

- The raspberry zero w card will be used when the limit distance is reach, it will take picture of the obstacle to know which path it should take.

- The arduino Uno card will handle the slither movment, will receive order to stop when the limit distance is reached (may ask the snake to get on line). Will receive order from the raspberry zero W to know which path it should follow.

### programm part

#### Arduino

nano:
- take the distance

Uno:
- slither motion
- cases depending on the python programme

#### Python
- receive the distance from arduino nano, if the distance is too short send a value to arduino Uno (to stop the slithering motion), then take a picture and read the information on it. 

### Etapes
#### 1) slither program for displacement arduino uno (servos)
- make a program which mimic the snake displacement

#### 2) ultra sound sensor program arduino nano 
- make a program to take the distances
- see how we will connect this arduino

#### 3) communication program raspberry pi zero W
- send message from arduino nano to raspberry pi
- treat the received datas
- send message to the arduino uno

#### 4) program traitement d'image raspberry pi zero W (Camera V2)
-

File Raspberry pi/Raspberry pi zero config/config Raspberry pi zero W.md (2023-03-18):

## Config Raspberry pi zero W

#### Intro:
    Ce document présent servira d'exemple pour une configuration de carte Raspberry pi Zero et résume ce document:
 [Raspberry_pi_Zero_W:_Installation_sans_écran_ni_clavier](https://thedatafrog.com/fr/articles/raspberry-pi-zero-headless-install/)

### Etapes:
###### - flasher une image de raspbian lite sur la carte micro SD
###### - configurer la connexion au résau wifi, et autoriser les connections à distance par ssh
###### - démarrer le pi et s'y connecter par ssh pour finaliser l'installation

####  flasher une image de raspbian lite sur la carte micro SD
ici on s'aide de ce document: [Installation rapide minimale d'un raspberry pi](https://thedatafrog.com/fr/articles/minimal-install-raspberry-pi/)

Raspbian est le système d'exploitation recommandé pour le raspberry pi. Il s'utilise un peu comme Ubuntu.

1) télécharger l'image de Raspbian lite [ici](https://www.raspberrypi.com/software/), nous utiliserons [celle-ci](liensgithub).

2) pour graver l'image on peut utiliser [Etcher](https://www.balena.io/etcher) si ce qui a était installer et une image(.img).
dns notre cas pour la gravure tout est géré dans le .exe installé avant.
imager
il suffit de:
- choisir la version voulu (pour un zero W on prendra un lite 32 bit) os selection
- séletionner l'espace de stockage (la carte mini SD)
- écrire (l'écriture et la vérification prendront environ 8 minutes).écriture

#### configurer la connexion au résau wifi, et autoriser les connections à distance par ssh

##### 1) Mise en service du SSH
les opérations suivantes peuvent être faites avec l'invite de commande windows mais ici nous utiliserons le terminal de la machine virtuel.

- on active le port USB lié à la carte SD pour la machine virtuelle.
    pour cela:
    - on ouvre la machine virtuelle et on sélectionne "configuration" MV
    - ensuite on choisit la section "USB" puis on ajoute un filtre usb port usb

- on peut maintenant rentrer les fichiers nécessaires pour le service ssh et le wifi.
    Il faut maintenant:
    - démarrer la machine virtuelle
    - aller dans "bootfs" qui sera lue comme un clé usb et y ouvrir le terminal ouverture du terminal
    - on y crée le fichier "ssh" avec la commande "touch ssh"
    - on crée ensuite le fichier "wpa_supplicant.conf" avec la commande touch wpa_supplicant.conf"
    - il faudra écrire dans ce fichier (on pourra utiliser la commande vim pour éditer le fichier)
    voici les commandes utilisés: command
    et voici le texte a rentrer dans le fichier "wpa_supplicant.conf": wpa config

On peut ensuite retirer la carte et la remettre au Raspberry pi, il faudra brancher celle-ci et attendre l'initialisation et la conexion au wifi qui devrait prendre un peu moins de 5 minutes.

##### 2) connexion SSH

une fois la connexion wifi établi, il nous faut relever l'adresse ip ou l'identifiant de la raspberry, si vous avez utilisez le partage de connexion de votre téléphone regardez dans les appareils connectés appareils connecté.

on va maintenant se connecté à la carte en SSH, pour cela on peut utiliser l'invite de commande windows(ou le terminal linux):
- on utilise la commande "ssh pi@raspberrypi" où "ssh pi@adresseip"(en remplaçant adresseip par votre adresse ip)
- on rentre ensuite le mot de passe "raspberry"

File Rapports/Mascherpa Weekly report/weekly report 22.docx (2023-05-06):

MASCHERPA Audric ROB 3 2022 / 2023

POLY-SNAKE

Weekly report n°22 from 02/05/23 :

In anticipation of the oral passage that will conclude our PolySnake project next week, we have focused on fine-tuning the details.

First, I started the week by adding capacitors to avoid voltage drops. My calculations having not borne fruit, I decided to use 1000µF capacitors which after a few tests seem to work very well on our project as shown in Figure 22.1.

Figure 22.1


After performing this step on all the servomotors, you can see the result in figure 22.2.

Figure 22.2

Once this step was completed and after restarting several welds which was the cause of bad contact and therefore poor power supply to the snake, I finally managed to power our project in 6.5V using 5 batteries varying between 1.2 and 1.5V and which allow to have a good movement of the snake using the Younousse program.


In addition, in order to be able to separate the Lego wheels, I decided to weld them together so as not to have any unpleasant surprises during the presentation of the project as in figure 22.3.1 and 22.3.2.


Figure 22.3.2

Figure 22.3.1

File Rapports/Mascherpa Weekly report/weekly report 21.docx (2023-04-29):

MASCHERPA Audric ROB 3 2022 / 2023

POLY-SNAKE

Weekly report n°21 from 17/04/23 :

Following the last session, I continued to work on the wiring of the PolySnake project. I was particularly interested in the connections between the servomotors and the pins of the Arduino board in order to be able to control them using the program we developed with my partner.

link : https://github.com/YOUSSNDR/PolySnake/tree/main/programmes

So to do this I just welded the orange cable to a male output in order to be able to connect the servomotor to the Arduino card as in figure 21.1.

Figure 21.1


After repeating this operation with all the servomotors, here is the visual result in figure 21.2.1 and 21.2.2.

Figure 21.2.1


Figure 21.2.2

After starting to test a basic program on each servomotor to check their proper functioning and the condition of all the welds, it appears that out of the 8 servomotors, 1 seems not to be powered and 2 others are connected to the same pin.

The next session will therefore be devoted to solving these problems in order to finally allow our snake to be able to operate without an external power supply.

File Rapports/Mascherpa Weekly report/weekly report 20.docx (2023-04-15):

MASCHERPA Audric ROB 3 2022 / 2023

POLY-SNAKE

Weekly report n°20 from 10/04/23 :

After the last session, I continued to work on the PolySnake connections according to Figure 20.1.


Figure 20.1

Thus, I had time to finish all the connections of the servomotors as can be seen in figure 20.2.1 and 20.2.2


Figure 20.2.1

Figure 20.2.2

During the next sessions, I will determine the capacitor adapted to our project. To do this, knowing that the calculation method gives us inconsistent results, I will test different types of capacitors until I find the one that suits and that best limits the voltage drops of the project.

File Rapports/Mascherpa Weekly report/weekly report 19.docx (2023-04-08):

MASCHERPA Audric ROB 3 2022 / 2023

POLY-SNAKE

Weekly report n°19 from 04/04/23 :


During the next sessions I will be responsible for wiring the servomotors to the power supply shown in figure 19.1

Figure 19.1

So, first of all I took care of determining the necessary capacitors in order to avoid a voltage drop in the system. I used the following equation :

E = 1/2 *C*( V1^2 - V2^2 )

With E the energy in J, C the capacitor in F and V1/V2 the voltage max and min from the voltage drop in V.


To calculate each of the elements and determine C I used the curve in figure 19.2.1 made using the assembly 19.2.2 and 19.2.3.

Figure 19.2.1

2.4V

6.4V

ΔT=250ms


Figure 19.2.2

Figure 19.2.3


So, knowing that the power supply used to operate the servomotors is 6.4V and 2A then we can determine the power in W then by knowing Δt determine the energy E:

P = V*I

P = 6,4*2=12.8W

But, E=P*Δt

E=12.8*250. 10^(-3) =3.2J

We can now determine the capacitor to use:

C= (2*E)/(V1^2 -V2^2)

C= (2*3.2)/(6,4^2 -2,4^2) =0.18F

Although the calculations were well carried out and the result must be divided by 8 due to the 8 servomotors in the Polysnake which are in parallel, 2.2mF per capacitor is an inconsistent value because it is much too large compared to the use that will to be made of it.

So, while waiting to understand where the error was made, we are going to use a 1000µF capacitor and check if the latter allows the voltage drops to be limited and change it if this is not the case.

Following this, I was able to start welding the servomotors to the power cables by adding connectors between each servomotor in order to be able to dismantle the snake once the cables are welded as

shown in figure 19.3.1 and 19.3.2.


Figure 19.3.1


Figure 19.3.2

The rest of the connections will be made during the next session.

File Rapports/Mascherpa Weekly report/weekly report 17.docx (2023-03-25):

MASCHERPA Audric ROB 3 2022 / 2023

POLY-SNAKE

Weekly report n°17 from 19/03/23 :

This session being shorter than the others, my partner and I decided to dedicate it to the search for a bug present on the movement of the polySnake. Indeed after the few tests carried out at the previous session it turned out that a servomotor did not work as we wanted.

This servomotor does not respect the instruction of the movement that we imposed on it with our program in figure 17.1.


Figure 17.1

Figure 17.2


After doing some research, it turned out that the problem did not come from the cables, nor from the Arduino card, nor from the servomotor itself, but it was a nice program that assignat two different instructions on a ping, which bugged the servo motor connected to this ping as shown in figure 17.2.

So after solving this problem we were finally able to perform the movement test on PolySnake but this time with all the body of our snake composed of 7 modules and the tail / head

Here is a link to the youtube video showing the movement of the snake using all these modules imprinted with the PETG filament :

https://www.youtube.com/watch?v=nyOi0dM7rbw

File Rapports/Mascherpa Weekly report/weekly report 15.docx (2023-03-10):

MASCHERPA Audric ROB 3 2022 / 2023

POLY-SNAKE

Weekly report n°15 from 07/03/23 :

Due to a printing problem, the 3D pieces could not be collected during this session. Thus the first tests in relation to the movements of the snake with wheels have been postponed until next week.


However, we can see in figure 15.1 part of the 3D printing of the snake's body made at the end of the week after the project session.

Figure 15.1

We can see on the left the head of the PolySnake which will contain the raspberry nano card as well as the camera and on the right the tail containing the battery and the Arduino card.

then, during the rest of this session, in order to help my partner in programming the raspberry nano card, research was carried out in order to program color and shape recognition. The ultimate goal is to allow our project to navigate in space using the red arrow as in Figure 15.2.

Figure 15.2

So here are the links to youtube videos explaining how raspberry cards and

their camera work:

https://www.youtube.com/watch?v=mNjXEybFn98

https://www.youtube.com/watch?v=-ZyFYniGUsw

https://www.youtube.com/watch?v=qfbPZbyYv8A

This video explains :

- The imports of important packages such as CV2
- Create ours trackbars
- Setting up the raspberry camera
- The PiRGBarray
- Setting up the color recognition

So the next session will be devoted to testing the movements of the snake with wheels and programming the card and the raspberry nano camera using OpenCV

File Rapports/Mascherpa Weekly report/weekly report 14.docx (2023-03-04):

MASCHERPA Audric ROB 3 2022 / 2023

POLY-SNAKE

Weekly report n°14 from 28/02/23 :

The new wheels and their supports have arrived, so the beginning of this session focused on the use of these wheels and their implementation on the 3D model.


The ultimate goal is to be able to use these wheels so that the snake can move forward only from the undulating movement and without any motorization. here is the arrangement of the wheels in figure 14.1.1

Figure 14.1.2

Figure 14.1.1

Figure 14.2


This figure is made up of 3 lego pieces 4488 (in figure 14.1.2) as well as two wheels. The objective is to be able to attach these lego pieces directly to the modules that make up the PolySnake so as not to have to use screws or nuts. We can therefore see in figure 14.2 a 3D model of the module with the area allowing the wheels to be accommodated.

Figure 14.3


We can therefore finally see a photo of the final rendering of this model with wheels in figure 14.3.

The next session will therefore be dedicated to printing all the modules as well as the head and tail of the snake and adding the wheels to them in order to check if our program allows our project to move without motorization.

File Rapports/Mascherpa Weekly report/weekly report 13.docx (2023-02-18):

MASCHERPA Audric ROB 3 2022 / 2023

POLY-SNAKE

Weekly report n°13 from 14/02/23 :

first of all, the wheels previously ordered coming from the USA, new wheels of French origin were favored in order to reduce the transport time and to have them as quickly as possible. Here are the wheels chosen in figure 13.1 very similar to the one chosen the last session.

Figure 13.1


Then, while waiting for the material to arrive, the 3D modeling of the body of the snake has been completed. The latter is inspired by all the models previously made in order to have the most optimal 3D pieces in terms of resistance, design, size, and utility.

Thus, in Figure 13.2 is a 3D model of the snake's head containing the rasebery nano card as well as the camera and space to add other items. Also in Figure 13.3 is a model of the snake's tail containing the battery (in orange) and the Arduino board (in dark blue).

Figure 13.3

Figure 13.2


It is important to emphasize that this 3D modeling aims to carry out the first tests of the advancement of the snake once the wheels have been delivered. This is why the aesthetic aspect has not yet been added.


finally, we can see in figure 13.4 the 3D modeling of the entire body of the snake.

Figure 13.4

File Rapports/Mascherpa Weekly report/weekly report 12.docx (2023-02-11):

MASCHERPA Audric ROB 3 2022 / 2023

POLY-SNAKE

Weekly report n°12 from 07/02/23 :

First of all, in view of improving our system as well as its resemblance to a snake, the engine initially planned will be removed and replaced by small wheels in figure 12.1. These last we will allow thanks to the undulating movement of the snake to move forward without using a motor.

Figure 12.1


Figure 12.2


Then, a large part of the session was centered on the wiring of the snake as well as the connection between all the servomotors, the battery, and the control board. An explanatory diagram in figure 12.2 has been produced for a better understanding.

We can see in green on the diagram the presence of a capacitor in order to avoid a drop in voltage due to the presence of a node where the cables of the servomotors will come to join the cables which will be welded to the 0 and 6.5V cables. Finally, everything will be connected to the Arduino card as well as the rasebery nano card.

To conclude, we concluded this session on the purchase of the necessary material for the brains of the snake as well as the Lego wheels and finally additional material to operate the crate rasebery nano and start programming the "brain" of the snake.

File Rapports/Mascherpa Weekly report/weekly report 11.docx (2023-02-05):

MASCHERPA Audric ROB 3 2022 / 2023

POLY-SNAKE

Weekly report n°11 from 01/02/23 :

Following the previous session and the arrival of the open day at the Polytech Sophia Nice engineering school, the focus during this session was on finishing the 3D modeling of the body of the Polysnake as well as the finalization of the program allowing him to move.


The objective was to fine-tune the details so that everything was ready for the open day. Thus, the modeling of the snake's body has been slightly modified such as the aesthetic appearance of the skull or even some slight details on the rigidity of the parts in figure 11.1.

Figure 11.1

Then, my binome and I finalized the snake program as well as its readability.

Here a link to the program : https://github.com/YOUSSNDR/PolySnake/tree/main/programmes

Finally, it was decided to use skid pads to be placed under the polysnake modules in order to reduce friction on the ground and to limit the power of the motor present in the crane of the project in figure 11.2.


Figure 11.2

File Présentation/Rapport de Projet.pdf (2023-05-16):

Rapport de Projet - PolySnake

De nos jours, le monde subit de nombreuses catastrophes naturelles qui font chaque année des centaines voire des milliers de victimes. Par exemple, selon le Discover Walks Glob , le tremblement de terre de Tangshan de 1976 était un tremblement de terre qui a frappé la région autour de Tangshan qui a ravagé 85% des bâtiments du. Le rapport officiel a fait état de 242 769 morts, mais lorsqu'on considère les disparus, les blessés qui sont décédés plus tard et les décès à Pékin et Tianjin, ce qui en fait le tremblement
de terre le plus meurtrier en Chine et l'une des principales
catastrophes en Chine.
Ainsi, afin d'optimiser la recherche des personnes disparues
dans ce genre de catastrophe, il est important de concevoir
des systèmes capables de se faufiler dans des espaces clos et


restreints afin de pouvoir venir en aide au survivant de ce genre de catastrophe naturelle.

Le poly-Snake doit donc pouvoir se faufiler dans des espaces inatteignables par l’homme pour y faire de la prise d’informations (ici prise d’image). On se limitera dans ce projet à un déplacement sur 2 axes. Pour cela nous nous sommes fixé les objectifs suivants :
- Concevoir un système embarqué intelligent
- Réaliser un programme imitant le mouvement d'un serpent
- Permettre au Poly-Snake de se diriger à l'aide de flèche rouge
- Modéliser en 3D les pièces constituant le corps du projet de A à Z
- Proposer un système entièrement démontable
- Utiliser des composants peu onéreux

A partir de ces objectifs, nous avons pu réaliser un cahier des charges listant les performances souhaitées de notre projet.

Cahier des charges :

| Fonction | Critère d’appréciation | Niveaux d’exigences
FC1 | Se déplacer | Avancer | 0,05 m/s
FC2 | Faire du repérage | Caméra | 1080p ; + 29 fps
FC3 | Détecter les obstacles | Capteur à Ultrason | ±0,3 cm
FC4 | Rentrer dans le coffre d’une voiture | Taille des modules | 40 x 30 x 20 cm

FC5 | Être esthétique | Couleur-forme | Choix libre
FC6 | Fonctionner sans branchement secteur | Batterie | +4066 mAh; +6V
FC7 | Être autonome | Mise en route -Autonomie | Bouton; [20;30 min]
FC7 | S’adapter au terrain | Résistance | Eau - Choc

Fonctionnement du PolySnake :

Une fois que notre cahier des charges était fixé, nous nous sommes intéressés au mouvement du serpent afin de comprendre comment se dernier fait pour avancer malgré son absence de membre extérieur. Il en découle que la réponse vient de la forme particulière de ces écailles. En effet les écailles du serpent sont conçues de sorte à ce qu’elles glissent sur le sol lorsqu’elles se retrouvent parallèles à la surface sur laquelle elle avance mais aussi à ce qu’elles viennent frotter le sol lorsqu’elles sont perpendiculaires à cette même surface.
C’est cette suite de frottement et de glissement qui permet au corps du serpent de se propulser sur le sol et c’est exactement le même principe que nous allons venir utiliser à l’aide de petites roues lego.


Effectivement, nous somme venu placer des roues passives en dessous de chaque module qui composent le corps du PolySnake pour remplacer ces écailles. Il en résulte que le serpent peut être propulsé vers l’avant simplement en envoyant une onde sinusoïdale le long du corps comme on peut l’observer sur le schéma ci-contre.


Par ailleurs, les modules observés précédemment sont des pièces entièrement réalisées en impression 3D qui permettent aux servomoteurs de se connecter les uns avec les autres. Cela permet à notre projet de pouvoir se mouvoir en ondulant sur le sol comme le ferait un vrai serpent uniquement en venant manipuler les mouvements des servomoteurs entre eux. On peut voir ci dessous une capture d’écran de la modélisation 3D du PolySnake avec la tête qui va venir accueillir l'émetteur à ultrason ainsi que la carte Raspberry pi zero W et la caméra Raspberry nano et la queue qui elle va venir accueillir la carte arduino et l’alimentation du projet.


Par la suite nous nous sommes intéressés au montage électrique du système complet. Ici le fonctionnement est simple, notre objectif était de venir alimenter en 6.4V les servomoteurs et la carte arduino qui composent notre serpent à l’aide de cinq piles en série variant entre 1.2V et 1.5V. De plus, le choix de l’alimentation n’a pas été pris au hasard. En effet c’est en se basant sur la datasheet des servomoteurs que nous avons pu déterminer la tension idéale pour alimenter correctement les servomoteurs sans venir les surcharger.

Schéma électrique du projet :


Algorithme de fonctionnement global du projet :

L’avance et le changement de direction du serpent sont possibles grâce au programme dans la carte arduino dont la fonction slither prend en entrée un décalage, une amplitude, une vitesse et une longueur d'onde, ce qui permet de faire osciller le serpent dans la direction désirée.
Le programme détient aussi une fonction pour arrêter le serpent si besoin.

La détection d'obstacle, la reconnaissance d’image et la prise de décision se font dans le même programme dans la raspberry pi zero W.

La distance entre le serpent et l’obstacle est constamment relevée, lorsque celle-ci est inférieur à 8 cm le serpent reçoit l’ordre de s'arrêter et la reconnaissance d’image commence.

La fonction de reconnaissance d’image cherche à savoir si la caméra détecte une flèche rouge, si oui alors elle relève la direction de celle-ci et l’envoi à la carte arduino pour que le serpent puisse prendre la nouvelle direction. Sinon le serpent est stoppé.


Le grand nombre de paramètres dans la fonction slither pourrait permettre plus de possibilité de mouvement (ex réduction des oscillation pour accéder à des espaces plus ou moins fin) mais pour le temps qui nous à été donné nous avons préféré nous concentrer sur faire avancer le serpent et lui permettre de changer de direction.


Estimation du prix du PolySnake :

Coût du projet:(9932,96€)
- matériel : (432,96€)
- ServoMoteur (TD-8135MG 180°) x8 (38,99€/pièces)
- carte Arduino Uno (12,98€)
- Carte Raspberry pi zero W (18,60€)
- Capteur à ultrason (HC-SR04) (5,99€)
- Caméra raspberry pi module V2.0 (25,80€)
- Roues (Lego) (32,90€)
- Condensateur (1000uF) x7 (0,78€/pièces)
- boitier à pile (9,99€)
- piles (x3 1,2V , x2 1,5V) (9,32€)
- Ingénieur (38K pour 1600h) en partant sur 200h/pers soit 4750€/pers

Les imprévus :
Pour ce qui à était modifié par rapport à la Bibliographie on peut trouver un changement au niveau des roues qui auraient dû être motorisées avec l’utilisation de moteur CC, le serpent final se déplace grâce au mouvement d’ondulation provoqué par les différents servomoteurs et aux frottement entre les roues et le sol. Cela nous à permis une réduction de la masse et taille du serpent, une réduction du coût total et aussi une réduction de la consommation.
On a aussi eu à ajouter des condensateurs ce qui n’était pas prévu.

Les problèmes :
L’un de nos plus grand problème était l’alimentation, Nous avions prévu à la base l’utilisation de batteries pour alimenter le projet cependant nous n’avons pas pu les commander, celles-ci ont été remplacées par des piles.
Un autre problème à régler lors du montage du serpent était celui des chutes de tension, pour régler ce problème nous avons placé des condensateurs tout au long du serpent.
Enfin pour ce qui est du capteur de distance, nous avons dû remplacer la carte arduino nano qui le contrôlait par une connexion direct à la raspberry pi zero W à cause de problèmes au niveau de la carte arduino nano, faire ce remplacement nous a aussi permis de réduire le nombre de composants.

Conclusion :

Pour conclure, ce projet à été pour nous l’occasion de travailler sur des thèmes placés au centre de l'ingénierie moderne telle que la modélisation, la conception, la programmation, etc… Il en découle que notre projet, bien que partiellement abouti, arrive à fonctionner sans aide extérieure.

En effet le PolySnake à l’aide de son alimentation 6.4V, de sa caméra raspberry pi, de son émetteur à ultrason et enfin de son programme, arriverai parfaitement à fonctionner sans aucune aide même si le programme centrale reliant la carte arduino à la carte raspberry pi n’est pas encore opérationnel.
C’est un aspect que nous souhaiterions travailler dans la suite de nos étude ainsi que le perfectionnement de la batterie et le jeu entre les servomoteurs afin de rendre notre projet 100% autonome et surtout tout terrain ce qui est actuellement l’un des plus gros problèmes du PolySnake, son manque de dynamisme sur les surfaces autres que parfaitement plane.

Bibliographie :

Bioinspired Robotic Snake:
Bioinspired Robotic Snake : 16 Steps (with Pictures) - Instructables (https://www.instructables.com/Bioinspired-Robotic-Snake/)

Snake locomotion :
Snake locomotion (louisiana.edu) (https://userweb.ucs.louisiana.edu/~brm2286/locomotn.htm)
Les serpents, ces animaux fascinants (free.fr) (http://squamata.free.fr/locomotion.htm)

The mechanics of slithering locomotion : https://www.pnas.org/doi/10.1073/pnas.0812533106

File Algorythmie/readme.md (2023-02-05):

## Algorithmie

Pour notre projet nous avons pour l'instant deux principaux programmes utiles à notre Robots:
- l'un nous permet d'imiter les ondulations des serpents "mouvement2"
- l'autre nous permet d'utiliser le moteur "moteurs2"

### moteur2
Ce programme est assez simple il nous permettra de faire avancer ou reculer le robot, pour cela on done la direction (marche avant/arrière) et une vitesse voulue sous forme d'une valeur analogique.
voici un test: [wheels_test](https://drive.google.com/file/d/1kCXxd9m7_tPdRNpz16n7oTgrz3TyLUi4/view?usp=share_link)

### mouvement2
Ce programme est un peu plus complexe, il agit sur les différents servos moteur et leur donne des angles à atteindre, ces angles sont déterminé a partir d'une fonction sinusoïdale ce qui nous permet de voir une ondulation. aussi cette fonction sinuisoïdale nous permet de controler différent éléments:
- l'amplitude du mouvement 
- la vitesse de propagation de l'onde
- la longueur d'onde.
tout ça pour donner un mouvement plus ou moins réaliste au robot.

voici un test ou on a une modification de l'amplitude, une modification de la vitesse et l'utilisation d'un décallage pour changer de direction:
[test_ondulation1](https://drive.google.com/file/d/18OSwVxILO8t3YWNuw0CFthk3nBTT0Grp/view?usp=share_link)
[test2_ondulation](https://drive.google.com/file/d/18mUrjYc68gUuUbowsBK2COEysheR3PN-/view?usp=share_link)

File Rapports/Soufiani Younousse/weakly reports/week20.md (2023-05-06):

## <p align=center> Session 23
<ins>02/05</ins>

### Arrow deterction program
I have took the work from where i left last week.
Now i have three version of the arrow detection program. 
We will sart with the [second program](https://github.com/YOUSSNDR/PolySnake/blob/dbf0446f182a6393fc1b76dd6d8bf0762ccefc0e/programmes/Cam%C3%A9ra/image%20recognition%205%20(youss)/testarrowrec5.2.py) which can now get the position of the tip of the arrow and get the center of the rectangle which can contain the arrow in order to get the direction of the arrow.
image pg2

For the [third program](https://github.com/YOUSSNDR/PolySnake/blob/2009bf68ff010cee0d42282d08546313a76a4bc5/programmes/Cam%C3%A9ra/image%20recognition%205%20(youss)/testarrowrec5.3.py) program i have changed the way the program recognise color to be more efficient the program now check if the color hue value of the pixel at the center of the contour is in a range of 0 tO 5 OR above 170 to know if it is red. this methode is more efficient as even if the brightness change the HVR mode color can help recognise the color.

for the [fourth program](https://github.com/YOUSSNDR/PolySnake/blob/2009bf68ff010cee0d42282d08546313a76a4bc5/programmes/Cam%C3%A9ra/image%20recognition%205%20(youss)/testarrowrec5.4.py) it mostly a rearrangment of the third programm.
here we choose to first check the contour to see if it match the one of an arrow and then check the color to see if it is red.
img prgm4

i have stock all the program needed for the snake on a file [snake 2](https://github.com/YOUSSNDR/PolySnake/tree/main/programmes/snake/snake2.0)

We had later trouble using the arduino nano (it would not upload any program). It may be a problem from arduino.
I will have to create a python program for the ultrasound sensor. We will be using the raspberry to control it.

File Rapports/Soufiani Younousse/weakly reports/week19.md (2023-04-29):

## <p align=center> Session 22
<ins>25/04</ins>

The work done this session can be split in two part:

### Testing part
We have strated the session by trying the [slithering program](https://github.com/YOUSSNDR/PolySnake/blob/dbf0446f182a6393fc1b76dd6d8bf0762ccefc0e/programmes/servomoteurs/D%C3%A9placement/snakewalkV5.0.0/snakewalkV5.0.0.ino) with the snake and his new connections done by Audric (my coworker).
It did not worked quite well, so we decided to use a [test program](https://github.com/YOUSSNDR/PolySnake/blob/ad8bc102a174c1b50114d60de3b588967cde8104/programmes/test/FKGXWP0K16PF6PV/FKGXWP0K16PF6PV.ino) on each servomotor one by one to see where does the problem come from.
We found out that two servomotors where sharing there connectics therefore they where both receiving two different orders at the same time.

### Arrow detection program
Before the holidays Nino gave me a program to test ([Nino's program](https://github.com/YOUSSNDR/PolySnake/blob/dbf0446f182a6393fc1b76dd6d8bf0762ccefc0e/programmes/Cam%C3%A9ra/image%20recognition%204%20(Nino)/testarrowrec4.py)). 
The program did worked but not exactly as i wanted,
as it detect not only the arrows but also all other contour.
imgpgNino

So i have started making my own program using pieces of all the four programs i have.
for now [my program](https://github.com/YOUSSNDR/PolySnake/blob/dbf0446f182a6393fc1b76dd6d8bf0762ccefc0e/programmes/Cam%C3%A9ra/image%20recognition%205%20(youss)/testarrowrec5.py) use the preprocess of the [second program](https://github.com/YOUSSNDR/PolySnake/blob/dbf0446f182a6393fc1b76dd6d8bf0762ccefc0e/programmes/Cam%C3%A9ra/image%20recognition%202/testarrowrec2.py) which make it easier to find the contours.

we next go through all the contours and take the medium color inside it thanks to the 'cv2.mean' command.

for now it only detect contour and give the medium color inside it.
there is what it looks like: imgmyprgm

We will next have to omprove the program to detect only arrow shapes in the image and among them only the one with a red color.

Ps: i have already improve the programm here you can find [my second program](https://github.com/YOUSSNDR/PolySnake/blob/dbf0446f182a6393fc1b76dd6d8bf0762ccefc0e/programmes/Cam%C3%A9ra/image%20recognition%205%20(youss)/testarrowrec5.2.py) which i will continue to improve till next report where i will also explain the new features.
here are images of the second program: img my second program

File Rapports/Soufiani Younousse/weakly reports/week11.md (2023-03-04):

## <p align=center> Session 14
<ins>14/02</ins>

- Work on the program:
    The goal was to modify the snake movement depending on the value send by python
    for that i've: 
    - listed the movement i wanted 
    - made a logical table out of them
    and so i was left with that : table_logique1 table_logique2
    (Maybe a little bit to much for the task) I have now all the movement i want to use and a number link to them.
    they are 9 cases:
        - line (snake in line)
        - slither (the snake go forward)
        - slither right (the snake take a right turn)
        - slither left (the snake take a left turn)
        - stop line (the snake get in line and wait)
        - stop left (the snake get in position to turn left then stop) 
        - stop right (the snake get in position to turn right then stop)
        - stop (the snake stop his mouvement)
            
        mouvement that we will later reduce to four:
        - line (snake in line)
        - slither (the snake go forward)
        - slither right (the snake take a right turn)
        - slither left (the snake take a left turn)
        - stop (the snake stop his mouvement)
    
    So i've tried this in a test program
    where all the case choice was made in the void loop but i have seen some issue with the slither loop in it, so i tried a new program [snakewalk-case2](https://github.com/YOUSSNDR/PolySnake/blob/15777205acda2ff8ac74c616b032026ad5cf631f/programmes/test/test%20mouvement/snakewalk-case2/snakewalk-case2.ino)
    here the case are directly in the slither loop but still they will be trouble in the program.
    I have to modify the program to be able to cut the slither fonction anywhere this would allow the stop case to work.
    i will try that on the next program and also keep the four cases to simplify it.

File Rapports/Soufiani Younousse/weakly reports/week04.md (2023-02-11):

## <p align=center> Session 4
<ins>15/11</ins>

gathering information about snake locomotion to come with a program which would mimic the snake ondulation.

we see in[Snake_Robot_Locomotion](https://www.youtube.com/watch?v=pv_MknD6jks&t=18s&pp=ugMICgJmchABGAE%3D) that their are more focused on how to pass large obstacle which for us will more likely be study after achieving making the snake serpentine while going forward.

in [how_Snakes_Move!](https://www.youtube.com/watch?v=7-AKPFiIEEw&pp=ugMICgJmchABGAE%3D ) we learn that:

- there are 4 differents locomotion for snakes 
    - srpentine locomotion
    - concertina locomotion
    - sidewinding locomotion
    - Rectilinear locomotion

those different methode are use for different envoronment.

Serpentine (lateral ondulation) is the one which we will study first as if we stick to the idea of making the robot on wheels it would at list looks like a snake.
so snake use this movement to push themselves off of objects and then push down where their body bends to move forward

the program create [snake_walkV2](https://github.com/YOUSSNDR/PolySnake/blob/d8df9ac458cd2a9e06b5fb9730dac2725eff6cc4/programmes/servomoteurs/D%C3%A9placement/snake%20walk%20V2/snake%20walk%20V2.ino) for now use only 3 servomotors which is less than the half of what we will use at the end. no test have been conduct for now with this programm as it has been finished at home.

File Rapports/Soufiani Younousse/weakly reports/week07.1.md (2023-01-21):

## <p align=center> Session 8
<ins>14/12</ins>

To start this new session we add one more module to the snake 
and fix some screw issues on the snake (some screw were to long and so were rubbing the snake).
seven_module_snake
Change of plan from what we wanted to do last week.
as with the control of his ondulation the snake can turn right and left we might use that to make it turn on wheels.
but for that we need to work the transition.
Two types of transition are to work on:
    - to make the snake form a line 
    - to turn

To line up:
    the snake will have to lose some amplitude if the path he is following is getting finer. in order to do that we use the slither function and drop the amplitude.
    But as the amplitude drops the movment looks slower so we also need to control the speed. After several test it seems that increasing the spead of 1°/s for every drop of 5 cm in amplitude give it a much better look.

To turn:
    We will need the snake to turn, for that we also use the slither function. when ask to turn the snake make the turn but to fast (it could break somthing). so we use a while loop and a delay fuction toslow down the turn.

there is a test where the turn is to strong [test turn and amplitude 1](https://drive.google.com/file/d/18OSwVxILO8t3YWNuw0CFthk3nBTT0Grp/view?usp=share_link)

there is the second test where the the amplitude and the turn where controlled [test turn and amplitude 2](https://youtu.be/qZ7Id3EbTI4)

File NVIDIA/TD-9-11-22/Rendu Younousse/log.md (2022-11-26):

#GESTION DES LOGS

pour la gestion des logs on utilise un logrotate.

##création du fichier:

le fichier doit être créé dans /etc/logrotate.d  en utilisant la commande : sudo vim savedata 

##contenu du fichier:
pour la gestion des logs tout d'abord je donne l'emplacement du fichier pour lequel j'utilise le logrotate et ensuit j'utilise 3 commandes:

le daily pour que le logrotate s'éxecute tous les jours.

"size 63M" pour lancer le logrotate dés que le fichier atteint ce volume, celui-ci sera prioritaire sur le daily.

Enfin, le "rotate 10" pour qu'il n'y ai pas plus de 10 fichiers log créé en même temps.

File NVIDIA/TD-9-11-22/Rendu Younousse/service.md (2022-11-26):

#services

##unit

Dans "Description" on donne le rôle du service.

"after=network.target" permet de lancer le service au moment où il y a une connexion internet.

##Service

dans "WorkingDirectory" on met le chemin du dossier contenant le ".sh" .

On donne l'utilisateur "User".

Type=oneshot pour que le programme ne se lance qu'une seule fois.

On donne le chemin du fichier  pour ExecStart.

##Install

"WantedBy=multi-user.target" définit l'état du service, on dit à "systemd" que le service doit débuter comme si il faisait partie du systeme de démarage.

##lancement:
pour le lancement du service tout d'abord on utilise "sudo systemcl daemon-reload" pour que le système prenne en compte les modifications sur les services.
Ensuite on lance le service avec "sudo systemctl start databasesaving.service".

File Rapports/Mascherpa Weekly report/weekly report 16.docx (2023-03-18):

MASCHERPA Audric ROB 3 2022 / 2023

POLY-SNAKE

Weekly report n°16 from 12/03/23 :


For this session, we did a lot of testing and checking out a theory we had regarding the motion of the snake without a motor. However, we first started by removing all the supports present on the many parts of the Polysnake once the 3D printing was finished in figure 16.1

Figure 16.1

So once the parts were completely cleaned, we were able to carry out the tests that we took on video and that we broadcast on the youtube platform.

https://www.youtube.com/watch?v=C6OPcSumDQM (straight ahead)

https://www.youtube.com/watch?v=HqG8QPvNAjo (movement to the left)

https://www.youtube.com/watch?v=mZjUm6wLaqU (movement to the right)

The idea we had was that more of the work on the slithering motion was made by the friction. And as it was pretty complicated to make a snake skin we have chosen Rubber wheels (as they will roll if the force that they receive is parallel to them and will be blocked more and more by friction as the force get perpendicular to them)

then we used these different programs to make it move:

- the first test worked but with some problems, as the snake makes too large movements, we have too much friction. However, we can modify the parameters on the movement of the snake in the program.
- After several tests, we realized that we had to find a balance between amplitude and wavelength (at some point to increase the amplitude but avoid too much friction, we had to increase the wavelengths which decrease in does the amplitude).
- we kept the characteristics that worked well with an offset of 3 (to fix a fault either at design or initialization that caused the snake to go slightly to the right) an amplitude of 43, a speed and a length of wave of 2 (these measurements have no equivalent with reality for the moment because the different characteristics change as we modify the parts so we must take measurements to find the given coefficient in reality) .

the line of code looked like this in code: slip (3,43,2,2)

here is the link to the programs : https://github.com/YOUSSNDR/PolySnake/tree/main/programmes/Classes/mouvement

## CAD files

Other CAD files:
Rendue CAO-FAO/SOUFIANI Younousse/boitier Soufiani_Younousse.f3d

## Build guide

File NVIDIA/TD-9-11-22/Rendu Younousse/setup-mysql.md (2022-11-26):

#setup mysql

##Installation MySQL:
- sudo apt update
- sudo apt install mysql-server

##Importer une base de donnée:
- sudo mysql "pour se conecter a mysql"
- "entrer le mot de passe"
mysql> source /home/younousse/polytech/TD_SQL/mysampledatabase.sql  "import la database"

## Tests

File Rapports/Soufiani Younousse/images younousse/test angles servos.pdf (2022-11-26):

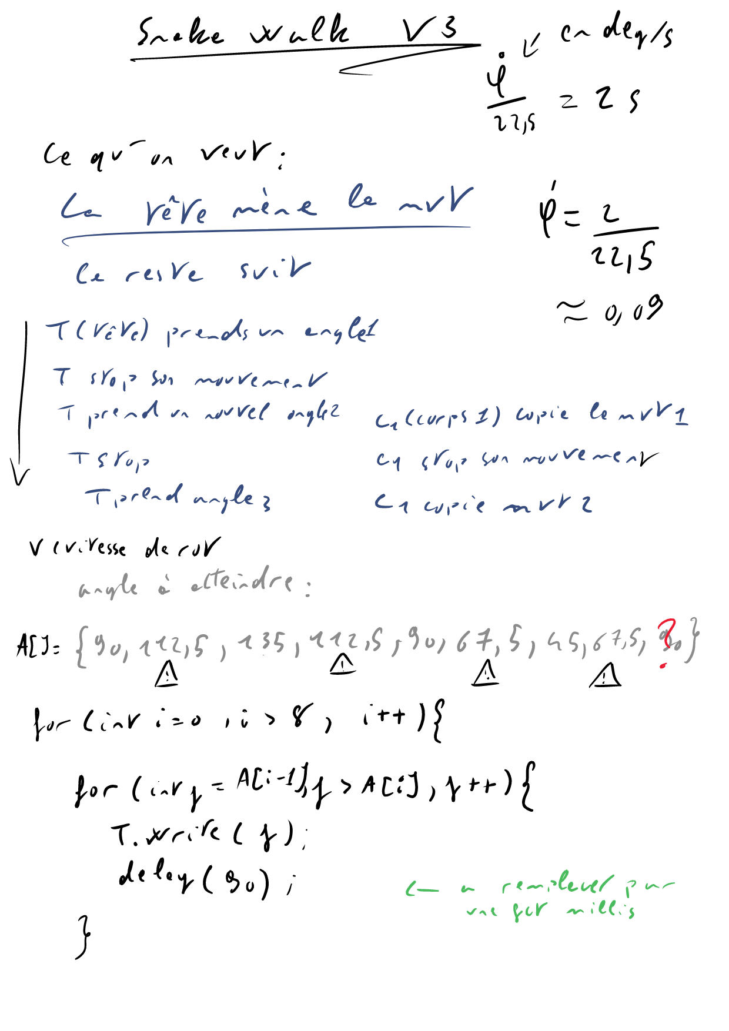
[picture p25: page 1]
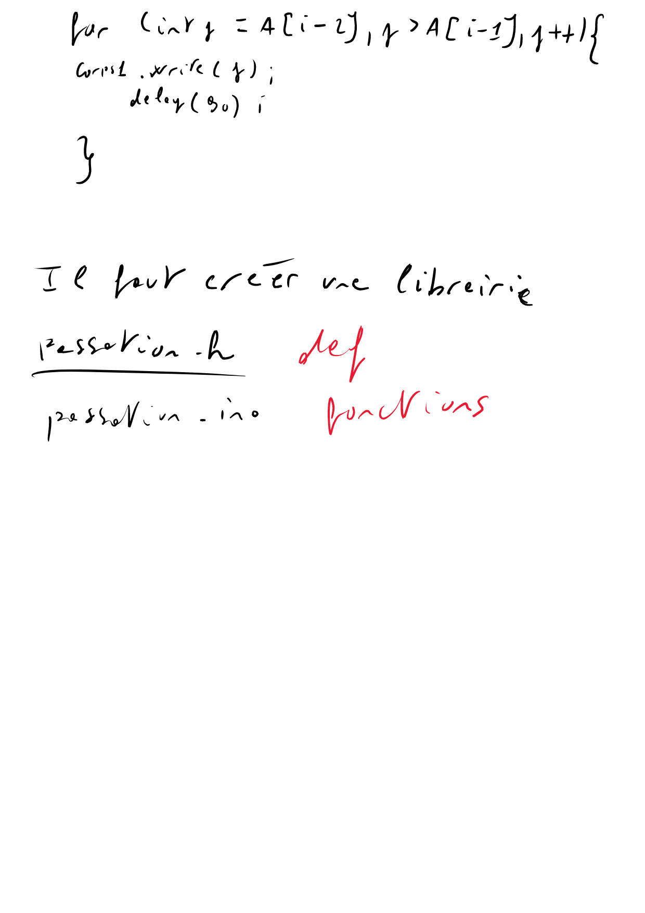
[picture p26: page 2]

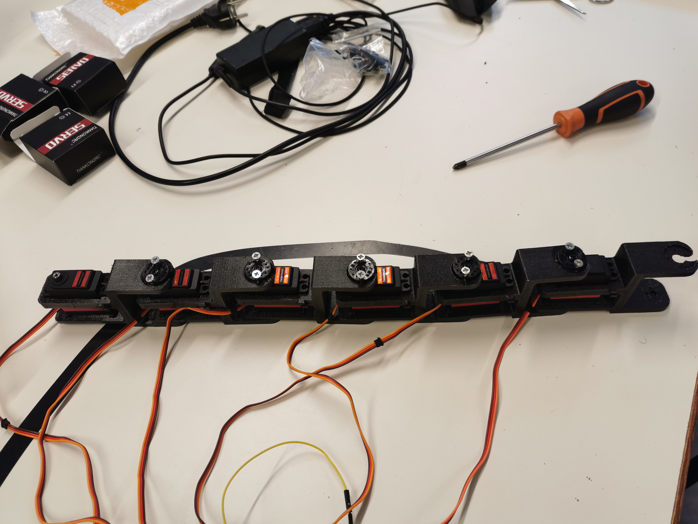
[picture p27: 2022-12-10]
Rapports/Soufiani Younousse/images younousse/test2.jpg

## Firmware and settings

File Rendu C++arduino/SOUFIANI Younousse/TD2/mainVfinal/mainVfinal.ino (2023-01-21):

#include "LettreMorseV3.h"
#include <string.h>
#include <Arduino.h>
using namespace std;

LettreMorse lm; //on appelle la classe LettreMorse avec lm
int tti= 250; //temps d'un ti
int code; 
char phrase[]="SOS ??!/. sos"; //phrase a traduire
int n;//taille de la liste
int i;//entier parcourant la liste
int t;// variable de temps =millis()
int T;// différence de temps =millis()-t

void setup() {
  Serial.begin(9600);   //initialisation du moniteur série
  pinMode(LED_BUILTIN, OUTPUT); //initialisation de la led
  Serial.println("I am ready...");
}

void loop() {
  //utilisation de phrase[]
  n= sizeof(phrase);
  while(i<n){
    code=phrase[i];
    code=verif(code); //on transforme les majuscules en miniscules
    lm.morsetr(code);  // application de la fonction morsetr appartenant à la classe LettreMorse
    Serial.print(char(code)); //affiche la lettre traduite
    if(lm.morse==""){}
    else if(lm.morse==" "){
      t=millis();
      T=0;
      // l'espacement entre chaque mot en morse est de 7ti (recommandé) or on a un ti de pause après les fonctions point et tiret soit 7ti total
      while (T<6*tti){
        T=millis()-t;
      } 
    }
    else{
      Serial.println(lm.morse); // affiche le code morse de la lettre
      Serial.print(" ");
      trad2(); //traduit le code morse en clignotement
    }
      i++;
  }
  //utilisation du moniteur série
  /*if (Serial.available()){ //si la machine reçoit quelque chose
    code=Serial.read(); // le message et lu lettre par lettre et on attribue a chaque fois une lettre a code 
    code=verif(code); //on transforme les majuscules en miniscules
    lm.morsetr(code);  // application de la fonction morsetr appartenant à la classe LettreMorse
    Serial.print(char(code)); //affiche la lettre traduite
    if(lm.morse==""){}
    else if(lm.morse==" "){
      t=millis();
      T=0;
      while (T<7*tti){
        T=millis()-t;
      } 
    }
    else{
      Serial.println(lm.morse); // affiche le code morse de la lettre
      Serial.print(" ");
      trad2(); //traduit le code morse en clignotement
      t=millis();
      T=0;
      while (T<3*tti){
        T=millis()-t;
      }
    }
  }*/

}


    void trad2(){
      for (int i=0;true;i++){
        if (lm.morse[i] == '.' ){ //on parcourt les caractères morse si on a un point on applique la fonction point
          point();
        }
            else if (lm.morse[i] == '-'){ //si on a un tiret on applique la fonction tiret
              tiret();
            }
            else { // sinon on sort de trad2
            break;
            }
          }
    }

    // réalisation d'un point "ti" allume la led 250ms,l'éteint et attend 250ms (temps entre chaque lettre)
    void point(){
      digitalWrite(LED_BUILTIN, HIGH);
      t=millis();
      T=0;
      while (T<tti){
        T=millis()-t;
      } 
      digitalWrite(LED_BUILTIN, LOW);
      t=millis();
      T=0;
      while (T<tti){
        T=millis()-t;
      }
      /*digitalWrite(LED_BUILTIN, HIGH);//led allumée
      delay(tti); //attante de 250ms pour les points
      digitalWrite(LED_BUILTIN, LOW);//led éteinte
      delay(tti);*/
    }

    //réalisation d'un tiret "taah" allume la led pendant 750ms et l'éteint puis attend 250ms pour l'espacement des lettres entre elles
    void tiret(){
      digitalWrite(LED_BUILTIN, HIGH);
      t=millis();
      T=0;
      while (T<3*tti){
        T=millis()-t;
      } 
      digitalWrite(LED_BUILTIN, LOW);
      t=millis();
      T=0;
      while (T<tti){
        T=millis()-t;
      }
          /*digitalWrite(LED_BUILTIN, HIGH);//led allumée
          delay(tti * 3); //attente de 750ms pour les tirets
          digitalWrite(LED_BUILTIN, LOW);//led éteinte
          delay(tti);*/
    }

    //on fait la vérification de si l'entrée est une majuscule ou une miniscule
    int verif(int code){
      if (code>=65 && code<=90){
        return code+32; //entre les majuscules les les miniscules en ascii(dec) il y a une différence de 32.
      }
      return code; // si c'est déjà une minuscule alors on y touche pas
    }

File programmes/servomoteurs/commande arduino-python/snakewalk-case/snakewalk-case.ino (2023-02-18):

#include <Servo.h>
#include <cvzone.h>
Servo myServos[10];


SerialData serialData(1, 1); //(numOfValsRec,digitsPerValRec)
int valsRec[1]; // array of int with size numOfValsRec 


float pi=3.14159;
int TotalNumberofServos=7; //change as required
float Shift = 2*pi/TotalNumberofServos; // Phase lag between segments
float Wavelengths, rads;
int  MaxAngleDisplacement;
bool arret=false;
int O=0;
int A=0;
int S=0;
int firstval;

void setup() {
  Serial.begin(9600);

  serialData.begin();

  myServos[0].attach(2);
  myServos[1].attach(3);
  myServos[2].attach(4);
  myServos[3].attach(6);
  myServos[4].attach(7);
  myServos[5].attach(8);
  myServos[6].attach(10);
  myServos[7].attach(11);
  myServos[8].attach(8);
  myServos[9].attach(5);

  
  //initialisation des servos formant une ligne droite
   for(int i=0; i<8; i++){  
    myServos[i].write(90);
    delay(15); 
  }
  delay(2000);

}


void straightline(){
  for(int i=0; i<10; i++){  
    myServos[i].write(90);
    delay(100); 
  }

}


void slither(int offset, int Amplitude, int Speed, float Wavelengths){
  MaxAngleDisplacement=abs(offset)+abs(Amplitude); //amount servo can rotate from the SetpointAngle without going out of the [0,180] degree range
  while(MaxAngleDisplacement>90){ //prevents a setpoint angle outside the rage of[0,180]
    Amplitude=abs(Amplitude)-1;
    MaxAngleDisplacement=abs(offset)+Amplitude;
  }
  for(int i=0; i<360; i++){
   rads=i*pi/180.0;     //convert from degrees to radians
   serialData.Get(valsRec);
   if(valsRec[0]=!firstval){
     break;
   }
   for(int j=0; j<8; j++){  
      myServos[j].write(90+offset+Amplitude*sin(Speed*rads+j*Wavelengths*Shift));
     }
     delay(10);
     if (arret==true){
       break;
     }
     if (arret==true){
       break;
     }
    }
   
}



void loop() {
  
    while(true){
    switch (valsRec[0]){
     case 0:
      while(valsRec[0]==0 || valsRec[0]==18 || valsRec[0]==20 || valsRec[0]==24){
        serialData.Get(valsRec);
        firstval==valsRec[0];
      }
     case 1:
      straightline();
      serialData.Get(valsRec);
      firstval==valsRec[0];
     case 2:
     arret=false;
      O=0;
      A=30;
      S=2.5;      
      slither(O,A,S,1.5);
      serialData.Get(valsRec);
      firstval==valsRec[0];
     case 4:
     arret=false;
      O=45;
      A=30;
      S=2.5;      
      slither(O,A,S,1.5);
      serialData.Get(valsRec);
      firstval==valsRec[0];
     case 8:
     arret=false;
      O=-45;
      A=30;
      S=2.5;      
      slither(O,A,S,1.5);
      serialData.Get(valsRec);
      firstval==valsRec[0];
     case 17:
      valsRec[0]=1;
     case 18:
      arret=true;      
      O=0;
      A=30;
      S=2.5;      
      slither(O,A,S,1.5);
      valsRec[0]=0;
     case 20:
     arret=true;      
      O=45;
      A=30;
      S=2.5;      
      slither(O,A,S,1.5);
      valsRec[0]=0;
     case 24:
     arret=true;      
      O=-45;
      A=30;
      S=2.5;      
      slither(O,A,S,1.5);
      valsRec[0]=0;
            }
        }
}

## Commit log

2022-10-01 création de nouveaux docs
2022-10-04 caractéristiques
    [caractéristiques servo+ moteur.ods]
2022-10-05 actualisation de la fiche caractéristique.
    [caractéristiques servo+ moteur.ods]
2022-10-05 infos à reformuler pour les intégrer à la Bibliographie
2022-10-06 Replacement des docs
2022-10-06 ajout de la biblio (non fini)
2022-10-07 travail sur la biblio + tableau
    [caractéristiques batteries.ods, caractéristiques servo+ moteur.ods, conso composant.ods]
2022-10-07 on affine les tableurs
    [caractéristiques batteries.ods, conso composant.ods]
2022-10-08 ajout de caractéristiques
    [caractéristiques composants.ods, caractéristiques servo+ moteur.ods, conso composant.ods]
2022-10-08 correctif conso
    [caractéristiques batteries.ods]
2022-10-08 réarangement
    [caractéristiques batteries.ods, caractéristiques composants.ods, caractéristiques servo+ moteur.ods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]
2022-10-08 correctif décalages dans la version fr
2022-10-27 test servo
2022-11-14 rendue CAO-FAO younousse
    [boitier VF Soufiani_Younousse.f3d]
2022-11-15 Travail Polysnake
    [boitier Soufiani_Younousse.f3d, boitier VF Soufiani_Younousse.f3d]
2022-11-16 ajjout des fonctions millis c++
2022-11-23 les services
2022-11-23 modif sur les services
2022-11-30 ajout de derniers coms
2023-01-14 A couple programs
2023-01-18 classes
    partition des programmes en classees
2023-04-15 Python Opencv program (camera)
2023-05-16 Rapport de projet
